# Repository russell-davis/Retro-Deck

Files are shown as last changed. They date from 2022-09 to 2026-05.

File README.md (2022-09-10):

# Retro Deck

*A programmable 8-key macro pad built on a [Raspberry Pi Pico](https://www.raspberrypi.com/products/raspberry-pi-pico/?variant=raspberry-pi-pico-w) with [CircuitPython](https://circuitpython.org/).*

### Credit where credit is due
I only adapted these designs. The real credit goes to the following people, without whom this project would not have been possible:
- Based on DaveM's [Stream Cheap](https://www.thingiverse.com/thing:2822140), the retro deck adds a slot for a screen mount to be inserted and uses a Pico instead of an Arduino Pro Micro. Dave outlines the steps to build a stream cheap [on his website](https://www.partsnotincluded.com/diy-stream-deck-mini-macro-keyboard/).
- The [Monitor](https://www.thingiverse.com/thing:3548757) was designed by TucksProjects.

## Goals I had for this project
- 3D print 8 key macro pad
- long press a key to activate a profile
- short press a key to activate the macro
- display current mode and last macro run on screen

## Bill of Materials
| Item | Qty | Price | Link |
|---|-----|---|---|
| Raspberry Pi Pico | 1 | 4-23 USD | [Adafruit (single)](https://www.adafruit.com/product/4864) • [Amazon (3pack)](https://www.amazon.com/dp/B08ZSKMJJD?ref=ppx_yo2ov_dt_b_product_details&th=1) |
| Switches | 1 | 14 USD | [Amazon](https://www.amazon.com/dp/B098BGPT6W?ref=ppx_yo2ov_dt_b_product_details&th=1) |
| Key Caps | 1 | 8 USD | [Amazon](https://www.amazon.com/dp/B01M023NFK?ref=ppx_yo2ov_dt_b_product_details&th=1) |
| Oled Screen | 1 | 7 USD | [Amazon](https://www.amazon.com/dp/B072Q2X2LL?psc=1&ref=ppx_yo2ov_dt_b_product_details) |
| Threaded Inserts  | 1 | 18 USD | [Amazon](https://www.amazon.com/dp/B08YYGRCBG?psc=1&ref=ppx_yo2ov_dt_b_product_details) |
| Hex Socket Bolts  | 1 | 19 USD | [Amazon](https://www.amazon.com/dp/B09D3DFHH4?psc=1&ref=ppx_yo2ov_dt_b_product_details) |
| Development Board | 1 | 15 USD | [Amazon](https://www.amazon.com/dp/B093GXJ64J?psc=1&ref=ppx_yo2ov_dt_b_product_details) |

## Contributing
Any help is appreciated. If you have any questions, feel free to reach out.

If you have any suggestions or improvements, please create a [feature request here](https://github.com/russell-davis/Retro-Deck/issues/new?template=feature_request.md) or [start a pull request here](https://github.com/russell-davis/rlukedavis.com/compare/)

Likewise, bugs reports can be submitted [here](https://github.com/russell-davis/Retro-Deck/issues/new?template=bug_report.md).

## A very quick Q&A
- **Why did you use a Pico instead of an Arduino Pro Micro?**
  - I like Raspberry Pi's, hadn't used a Pico yet, and had $6. I also wanted to try out CircuitPython.
- **Can it launch apps?**
  - If you can launch it with a keyboard shortcut, then yes*.
  - *I haven't tried though. I'm primarily using it to with keyboard shortcuts that are more complicated than I want to remember.
- **Can I use it to play games?**
  - Sure, I guess. I haven't tried it yet. I imagine you'll have some ghosted keys, as this codebase is not rock solid (yet).
- **Your code is shit.**
  - I know. I'm working on it. Please contribute by starting [a feature request](https://github.com/russell-davis/Retro-Deck/issues/new?template=feature_request.md) to make it better

# Configuration

### mappings.json
The easiest way to get started configuring your Retro Deck is to duplicate and rename the `example-mappings.json` copy to `mappings.json` and edit it to represent your wiring.

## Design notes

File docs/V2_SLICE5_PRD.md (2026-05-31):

# V2 Slice 5 — Reliability + Diagnostics

## Why

Two issues block daily use of the Retro Deck:

1. **Keyboard "hijacking."** The host emits keypresses via two separate `ydotool`
   processes (press, wait 30 ms, release — `dispatch.ts`). If anything interrupts
   that window (release process error, an overlapping double-fire, the daemon
   dying mid-press) a modifier (Ctrl/Shift/**Super**) is left held *down at the
   virtual-keyboard level, system-wide*. Every later keystroke then carries the
   stuck modifier — the device appears to "hijack" the whole keyboard.

2. **Mis-calibrated input.** Long/short presses fire more than once and chords
   behave inconsistently. Three root causes:
   - **No chord decision window.** Pressing 1+3 "together" sends `press 3 held=[]`
     then `press 1 held=[3]`; the host fires the single-button "3" action *and*
     the "1+3" chord, order depending on which switch lands first.
   - **No tap/hold/double-tap concept.** The device sends raw press/release; the
     host fires on every press. Hold slots aren't wired.
   - **One event per 10 ms loop.** The firmware drains only a single keypad event
     per `time.sleep(0.01)` tick, so near-simultaneous presses are serialized
     ~10 ms apart — it *manufactures* gaps that corrupt chord detection.
   - We can't currently distinguish "device emitted 2" from "host saw 1 twice"
     because there is no sequence number on the wire.

We will not guess thresholds. We instrument first, measure the real limits
(serial throughput, keypad debounce floor, injection latency), then build the
smart input engine on measured values.

## Non-goals (this slice)

- The smart tap/hold/double-tap/chord classifier (Slice 6 — needs data first).
- Replacing ydotool with a self-managed uinput device (future hardening note below).

## Deliverables

### A. Keyboard reliability (`host/src/server/keyboard.ts`, `dispatch.ts`)
- `emitChord(codes)` — press + release in **one** `ydotool key` invocation, so a
  modifier can never be stranded between two processes.
- `releaseAllModifiers()` — best-effort release of all L/R modifier codes.
- Call `releaseAllModifiers()` on daemon startup (clears leaks from a prior crash).
- `POST /api/panic` + a UI "release all keys" control.

### B. Instrumented firmware (`firmware/code.py`)
- Monotonic `seq` on every outbound message → host detects drops (seq gap) and
  duplicates (seq repeat).
- Drain the **entire** keypad event queue each loop; tighten loop to ~1 ms.
- `ready` reports `version`, `buttons`, `pins`, `debounce_ms`.
- Runtime `config` command: `heartbeat_ms` (0 = off, default), `debounce_ms`
  (recreates `keypad.Keys`). Instrumentation is opt-in; the device is quiet in
  normal use.
- `ping`/`pong` echoes the host timestamp (`ht`) so the host measures round-trip
  latency with no clock sync.
- Backward compatible: extra fields are ignored by the existing host paths.

### C. Deploy tooling (`host/scripts/deploy.ts`, `bun run deploy`)
- Find CIRCUITPY by filesystem label (never a hardcoded path), mount via
  `udisksctl` if needed, copy `firmware/code.py` + `firmware/boot.py`, rsync
  `lib/`, `sync`. `--eject` to unmount. Target < 10 s.

### D. Diagnostics core + CLI + web tab (`host/src/server/diagnostics.ts`, `scripts/diag.ts`, client `Diagnostics` tab)
- Shared analyzer: per-button state, inter-press gaps, press→release durations,
  dropped/duplicate frames (via seq), device-`t`-vs-host-arrival latency + jitter,
  sustained events/sec, ping/pong RTT.
- Scripted test routines: tap×N, hold, double-tap, rapid-fire, two-button chord,
  all-buttons, and a ping stress test to find the serial ceiling.
- CLI for remote/SSH use; web tab for live timeline + gauges. Both consume the
  same core and can replay a recorded capture (so it's testable without hardware).

### E. Smart input engine — Slice 6, deferred
Host-side classifier (debounce floor, chord window, double-tap gap, hold
duration) tuned from Slice 5 measurements.

## Future hardening note
ydotool injects through `ydotoold`'s virtual keyboard, which outlives our daemon —
that's why a leaked modifier persists. A self-managed `/dev/uinput` device owned
by the daemon process would let the kernel auto-release all keys the instant the
daemon exits. Tracked for a later slice.

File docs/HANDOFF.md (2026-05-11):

# Retro Deck V2 Rewrite

## What This Is

The Retro Deck is a physical 8-key macro pad built on a Raspberry Pi Pico running CircuitPython. The original codebase was written before the owner knew what they were doing — it works, but it's messy and limited. This V2 rewrite starts from scratch with a clear goal: turn the Retro Deck into a first-class **agent tool** — a physical peripheral that can trigger, interact with, and be controlled by Claude Code agents or other AI workflows.

## Goal for This Session

Design and implement the V2 architecture. The rewrite should be clean, intentional CircuitPython — but more importantly, the device should be capable of acting as a hardware input/output bridge for agent-driven workflows. What that means exactly is an open question to explore with the user at session start.

## Decisions Already Made

- **Branch**: `feature/v2-rewrite` (on `russell-davis/Retro-Deck`)
- **Hardware**: Raspberry Pi Pico, 8 mechanical switches, OLED display, CircuitPython
- **Scope**: Full rewrite — don't salvage the old `code.py`, start clean
- **Direction**: Make it an "agent tool" — the device should be useful as part of an AI/Claude workflow, not just a standalone macro pad

## What's Been Done

- Cloned repo to `~/Work/retro-deck`
- Created branch `feature/v2-rewrite`

## Start Here

1. Read the existing `code.py` and `example-mappings.json` to understand what V1 did
2. Read `src/` and `lib/` to see what modules exist
3. Ask the user: **"What does 'agent tool' mean to you here?"** — does the Pico talk to the host over serial USB? Does it trigger webhooks? Does it register as a HID device that sends signals to a running agent? The answer shapes the entire architecture.
4. Once direction is clear, design the V2 module structure before writing any code

## Open Questions

- What is the communication model? (USB serial, HID, USB CDC, webhook, other?)
- Should the device be host-driven (agent sends commands to Pico) or device-driven (Pico sends events to agent)?
- Does the OLED display get driven by the Pico itself, or can the host push display content?
- Should profiles/macros still exist in V2, or is the key mapping entirely agent-controlled?
- Config format: keep JSON, or move to something simpler/more expressive?

## References

- Original repo: `https://github.com/russell-davis/Retro-Deck`
- Existing code: `code.py`, `example-mappings.json`, `src/`, `lib/`
- CircuitPython docs: `https://docs.circuitpython.org`
- Device is currently plugged in at `/dev/sda1` (label: `CIRCUITPY`) — not auto-mounted

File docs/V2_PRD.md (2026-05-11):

# Retro Deck V2 — Product Requirements Document

> **Status:** Draft v1
> **Audience:** Implementation team, issues writer, future maintainers
> **Source of truth for V1 state:** `V2_REWRITE_ANALYSIS.md`
> **Owner:** rld

---

## 1. Overview

Retro Deck V2 is a ground-up rewrite of the firmware, host integration, and configuration tooling for an 8-key + OLED USB macro pad built on a Raspberry Pi Pico (RP2040, CircuitPython). V1 is a self-contained HID emitter: every button is wired in Python to a hardcoded keystroke, and the host has no idea the device exists beyond stock USB descriptors. V2 inverts that relationship.

In V2, the **host owns the brains** and the **Pico is a thin I/O peripheral**:

- The Pico reports raw button events (press / hold / release with durations) and renders whatever the host tells it to render on the OLED.
- A host-side **Bun/TypeScript daemon** owns the config, dispatches actions, drives the OLED, and exposes hooks (e.g. for Claude Code) that other processes can call.
- A **configuration UI** edits the config live, and the daemon hot-reloads it.
- Three distinct **action types** are supported per button: `keypress` (Pico emits HID directly), `bash` (host shell command), and `function` (host TypeScript module imported and invoked).
- **Profiles** are infinite, named, and stored on the host. Switching is host-driven, with a configurable on-device gesture (default: long-press a designated button).

The result: any new behaviour — a deploy command, an "approve PR" hotkey, a Claude Code "yes/no" prompt, a new profile for a different app — is a config edit on the host, not a firmware re-flash.

---

## 2. Goals & Non-Goals

### 2.1 Goals

| # | Goal | Why it matters |
|---|---|---|
| G1 | Two-way structured comms over USB CDC between Pico and host | Unblocks every other goal |
| G2 | Host-owned config, hot-reloadable, no firmware edits to add/change actions | Configuration is a TypeScript/JSON workflow, not a CircuitPython workflow |
| G3 | Three action types: `keypress`, `bash`, `function` | Covers the realistic action surface (HID, shell, custom TS logic) |
| G4 | Infinite named profiles with host-driven switching | Removes V1's hardcoded 3-profile / IndexError limit |
| G5 | Host pushes display content; OLED shows current profile + per-button labels | The user can read what each button does without pressing it |
| G6 | Non-blocking firmware loop (asyncio) — concurrent button + serial + display | No more `time.sleep(1.5)` stalling the entire device |
| G7 | Persistent active profile across reboots (host-side) | Reboot resumes where you left off |
| G8 | Configuration UI (TUI or webapp) showing all profiles, all 8 slots, live device state | Editing JSON by hand is fine but not the primary workflow |
| G9 | Deploy tooling for fast firmware iteration (CIRCUITPY mount/rsync/unmount) | A code-edit/test cycle of seconds, not minutes |
| G10 | Graceful error reporting from device to host (and to user via OLED) | Replace V1's silent drop-to-REPL on exceptions |
| G11 | Claude Code hook integration via HTTP endpoints on the daemon | Use the deck as an approval surface for agent prompts |

### 2.2 Non-Goals

| # | Non-goal | Reason |
|---|---|---|
| NG1 | WiFi / Bluetooth / network comms from the Pico | Hardware is base Pico (no W). USB is sufficient. |
| NG2 | Multi-host / multi-device pairing | One Pico, one host. Identity disambiguation deferred. |
| NG3 | Per-key RGB or per-key LCD | Hardware is monochrome SSD1306 OLED + plain switches. |
| NG4 | Cross-OS support beyond Linux | Owner runs Linux (Arch/Omarchy). macOS/Windows untested in V2. |
| NG5 | Encryption / authentication on the serial channel | USB-attached peripheral on a single-user machine. |
| NG6 | Replacing CircuitPython with MicroPython or bare-metal | CircuitPython is intentionally chosen for iteration speed. |
| NG7 | Backwards compatibility with V1 profiles or `mappings.json` schema | Clean break. V1 is removed. |
| NG8 | OTA firmware updates over USB CDC | Deploy is a host-side rsync to CIRCUITPY mount. |
| NG9 | Mouse / consumer-control HID in v2.0 | Bundled libs exist; deferred to v2.1+. |

### 2.3 Success Criteria

- A new action can be added by editing a single JSON file on the host and saving — no firmware reflash, no daemon restart.
- A new profile can be added the same way.
- The OLED shows the active profile name persistently and updates within 100ms of a profile switch.
- All 8 buttons work for press, hold (with duration), and release events. No button gesture crashes the firmware.
- The daemon survives Pico unplug/replug without a manual restart.
- `bun run deploy` syncs firmware to the device in under 10 seconds.

---

## 3. System Architecture

### 3.1 ASCII Diagram

```
 ┌──────────────────────────────────────────────────────────────────────┐
 │                              HOST (Linux)                            │
 │                                                                      │
 │   ┌──────────────────┐     ┌────────────────────┐    ┌─────────────┐ │
 │   │   Config UI      │     │   retro-deckd      │    │  Claude     │ │
 │   │   (TUI/webapp)   │◄───►│  (Bun/TS daemon)   │◄──►│  Code /     │ │
 │   │                  │ HTTP│                    │HTTP│  external   │ │
 │   │  - profile list  │     │  ┌──────────────┐  │    │  tools      │ │
 │   │  - 8 slots/prof  │     │  │ ConfigStore  │  │    └─────────────┘ │
 │   │  - live state    │     │  │ (JSON, hot-  │  │                    │
 │   │  - test buttons  │     │  │  reloaded)   │  │                    │
 │   └──────────────────┘     │  └──────┬───────┘  │                    │
 │                            │         │          │                    │
 │   ┌──────────────────┐     │  ┌──────▼───────┐  │                    │
 │   │ ~/.config/       │◄───►│  │ ActionExec   │  │                    │
 │   │ retro-deck/      │ R/W │  │ (keypress/   │  │                    │
 │   │   config.json    │     │  │  bash/fn)    │  │                    │
 │   │ ~/.local/share/  │     │  └──────┬───────┘  │                    │
 │   │ retro-deck/      │     │         │          │                    │
 │   │   state.json     │     │         │          │                    │
 │   └──────────────────┘     │         │          │                    │
 │                            │  ┌──────▼───────┐  │                    │
 │                            │  │ SerialMgr    │  │                    │
 │                            │  │ (CDC, JSONL) │  │                    │
 │                            │  └──────┬───────┘  │                    │
 │                            └─────────┼──────────┘                    │
 │                                      │ /dev/ttyACM1                  │
 └──────────────────────────────────────┼───────────────────────────────┘
                                        │ (USB CDC + USB HID, same cable)
 ┌──────────────────────────────────────┼───────────────────────────────┐
 │                              DEVICE  │ (Pi Pico, CircuitPython)      │
 │                                      │                               │
 │                   ┌──────────────────▼───────────┐                   │
 │                   │       code.py (asyncio)      │                   │
 │                   │                              │                   │
 │  ┌─────────────┐  │  ┌────────────────────────┐  │  ┌─────────────┐  │
 │  │ 8 switches  ├─►│  │ ButtonScanner (keypad) ├──┼─►│ usb_cdc.data│  │
 │  │ GP20,19,18, │  │  └────────────────────────┘  │  │ (events out)│  │
 │  │ 17,11,12,   │  │                              │  └─────────────┘  │
 │  │ 13,14       │  │  ┌────────────────────────┐  │                   │
 │  └─────────────┘  │  │ SerialReader (cmds in) ◄──┼──┐                │
 │                   │  └──────────┬─────────────┘  │  │                │
 │  ┌─────────────┐  │             │                │  │                │
 │  │ SSD1306     │◄─┼──┌──────────▼─────────────┐  │  │                │
 │  │ OLED 128x64 │  │  │ DisplayRenderer        │  │  │                │
 │  │ I2C GP0/1   │  │  └────────────────────────┘  │  │                │
 │  └─────────────┘  │                              │  │                │
 │                   │  ┌────────────────────────┐  │  │                │
 │  ┌─────────────┐  │  │ HIDEmitter (Keyboard)  │◄─┼──┘                │
 │  │ USB HID     │◄─┼──┤ for "keypress" actions │  │                   │
 │  └─────────────┘  │  └────────────────────────┘  │                   │
 │                   └──────────────────────────────┘                   │
 └──────────────────────────────────────────────────────────────────────┘
```

### 3.2 Roles at a glance

| Layer | Owns | Does NOT own |
|---|---|---|
| **Pico firmware** | Button scanning, HID emission for `keypress` actions, OLED rendering, serial framing | Action dispatch, profiles, action semantics, what to show |
| **Host daemon** | Config, profiles, action execution (`bash`/`function`), display content decisions, persistence, external HTTP integrations | Raw button electricals, HID emission for keypress (Pico does this directly to reduce latency), OLED pixel drawing |
| **Config UI** | Editing experience, validation, "test" affordances | Live action execution (delegates to daemon), serial comms |

### 3.3 Why the Pico emits keypress HID directly (not via the host)

For `keypress` actions, the Pico has the HID device on the same USB connection and can emit a keystroke immediately on button press without a host round-trip. The action **type** is configured on the host, but for `keypress` actions the **actual keys** are pushed to the Pico (via a `bind` message — see §9) so it can fire them with zero host involvement during the press. This keeps `keypress` latency at hardware speed and avoids a "host crashed → keys don't work" failure mode for the most common action type.

`bash` and `function` actions go through the host because they have to.

---

## 4. Component 1: Pico Firmware (CircuitPython)

### 4.1 Responsibilities

The Pico firmware is intentionally minimal:

1. Scan 8 buttons; emit press / hold-tick / release events with millisecond timestamps over USB CDC.
2. Render OLED content as instructed by the host (header, per-button labels, transient toasts, error banners).
3. Emit USB HID keystrokes for buttons that have been bound to a `keypress` action by the host.
4. Maintain a small in-memory cache of: current profile name, per-button labels, per-button keypress bindings.
5. On boot, send a `ready` handshake and wait for the host to push initial state.
6. Surface fatal errors as a banner on the OLED *before* dropping to REPL.

The firmware does **not** know:

- What profiles exist (only the currently active one's labels and bindings).
- What `bash` or `function` actions exist (those are entirely host-side).
- How to switch profiles by itself (it sends a "long-press" event; the host decides what that means).

### 4.2 boot.py requirements

`boot.py` must enable USB CDC data channel (the second serial endpoint):

```python
# boot.py
import usb_cdc
usb_cdc.enable(console=True, data=True)  # data=True enables /dev/ttyACM1
```

**Notes:**
- `console=True` keeps the REPL on `/dev/ttyACM0` so we can still debug via Mu/Thonny/screen.
- `data=True` adds the second endpoint at `/dev/ttyACM1` — this is the channel used by the host daemon. *(Exact device path may vary by enumeration order; the host daemon must auto-discover via VID/PID or by trying `/dev/ttyACM*` and looking for the `ready` handshake.)*
- `boot.py` runs at hard reset and is what configures USB endpoints (which can only be set up before USB enumeration). Soft reload does not re-run it.

### 4.3 Serial Protocol (overview, full spec in §9)

- **Transport:** USB CDC, `usb_cdc.data` endpoint (`/dev/ttyACM1`).
- **Encoding:** UTF-8.
- **Framing:** newline-delimited JSON (JSONL). Each message is a single-line JSON object terminated by `\n`. Values must be valid JSON — embedded newlines inside string values are JSON-escaped (`\n`) per the spec; the line delimiter is the literal byte `0x0A` outside any string token.
- **Direction tags:** Each message has a `type` field. Pico→Host messages are reactive/eventy; Host→Pico messages are imperative/setter-y.
- **Versioning:** A `protocol` field is sent only in the `ready` and `hello` handshake messages (see §9). All other messages omit it; both sides assume the version handshake.

### 4.4 Button event model

Three event types are emitted per button, all reaching the host:

| Event | When | Payload |
|---|---|---|
| `press` | Edge: button transitions from released to pressed | `{ id, t }` |
| `hold` | Every 250ms while held, after the first 500ms | `{ id, t, duration_ms }` |
| `release` | Edge: button transitions from pressed to released | `{ id, t, duration_ms }` |

- `id`: 1–8, the logical button index (post-mapping, see §6.2).
- `t`: monotonic milliseconds since Pico boot (`supervisor.ticks_ms()`).
- `duration_ms`: total time held so far (for `hold`) or total time pressed (for `release`).

**Press semantics on the host:**
- A *short press* is a `press` followed by a `release` with `duration_ms < long_press_ms` (default 1500ms; configurable).
- A *long press* is a `release` with `duration_ms >= long_press_ms` (or, equivalently, the host can act on the first `hold` event whose `duration_ms` crosses the threshold for instant feedback).
- The host owns the threshold; the Pico just streams raw events.

**Implementation:** Use CircuitPython's `keypad.Keys` for non-blocking, debounced edge detection. Run the scanner inside an asyncio task at ~100Hz tick (the library does its own debouncing).

### 4.5 OLED rendering model

The OLED has three render zones:

```
 ┌──────────────────────────────┐
 │ HEADER       (line 1, small) │   ← profile name, e.g. "OBS"
 ├──────────────────────────────┤
 │                              │
 │   BODY      (lines 2–6)      │   ← 8 button labels in a 4x2 grid,
 │                              │     OR transient toast,
 │                              │     OR error banner (overrides body)
 │                              │
 ├──────────────────────────────┤
 │ STATUS  (line 7, small)      │   ← e.g. "● ready"  /  "● running…"
 └──────────────────────────────┘
```

- Default body: a 4×2 grid of button labels (buttons 1–4 top row, 5–8 bottom row). Labels truncated to fit.
- Toast: a transient large-font centred message after a press (configurable TTL, default 1500ms), then revert to grid.
- Error banner: full-body inverted (white-on-black) message with the most recent error, until cleared by host or auto-dismissed after `display.errorTtlMs`.

The host pushes content via `display.set_layout`, `display.toast`, `display.error`, `display.clear_error` messages (see §9). The Pico does no semantic decision-making about display state; it renders what it's told.

**Font:** `terminalio.FONT` (built-in 6×8 monospace) for v2.0. If labels need to be longer than ~10 chars per cell, v2.1 can vendor `adafruit_display_text` source `.py` and add scrolling — but v2.0 truncates with an ellipsis.

### 4.6 HID for keypress actions

- The Pico keeps a dict `keypress_bindings: dict[int, list[str]]` — button id → list of keycode names (e.g. `["CONTROL", "SHIFT", "R"]`).
- This dict is populated on profile-load by a `bind.set` message from the host.
- On a `press` event, the Pico checks the dict and (if a binding exists) emits the HID report immediately, then releases the keys after a short delay (~30ms) — simulating a tap.
- Only `keypress` actions populate the dict. `bash` and `function` actions do not — those buttons send their event to the host and let the host do the work.
- The Pico still emits the `press`/`release` events to the host even if it fires a HID report locally — the host is the system of record for "what just happened."

**Keycode parsing:** The host sends keys as a list of canonical names (e.g. `["CONTROL", "SHIFT", "F5"]`). The Pico maps these to `adafruit_hid.keycode.Keycode` attributes by `getattr`. Unknown names cause the binding to be rejected with an `error` reply naming the bad key.

### 4.7 asyncio loop design

CircuitPython 8+ ships with `asyncio`. The main loop is a small set of cooperating tasks:

```python
async def main():
    await asyncio.gather(
        button_scanner_task(),     # keypad.Keys → emit events
        serial_reader_task(),      # usb_cdc.data → parse JSON → dispatch
        display_render_task(),     # subscribe to display state changes
        heartbeat_task(),          # emit a "tick" every 5s for liveness
    )
```

- Tasks communicate via `asyncio.Queue` instances.
- The serial reader is a pure router: it parses a line, validates `type`, and pushes onto the appropriate queue (display queue / bindings queue / etc.).
- No `time.sleep()` anywhere — every wait is `await asyncio.sleep(...)`.
- Errors caught at task boundary and reported to host via an `error` message; firmware does not crash.

### 4.8 Persistence on the Pico

- **None.** The Pico does not remember the active profile, last action, or anything else across reboots.
- The host pushes the full state on every connect (`hello` from the host, in response to the Pico's `ready`).
- This keeps the Pico stateless and the host as single source of truth.

### 4.9 GPIO mapping

Hardware pin assignments are unchanged from V1:

| Button id | GPIO |
|---|---|
| 1 | GP20 |
| 2 | GP19 |
| 3 | GP18 |
| 4 | GP17 |
| 5 | GP11 |
| 6 | GP12 |
| 7 | GP13 |
| 8 | GP14 |

OLED I2C: SDA=GP0, SCL=GP1, address `0x3C`.

The pin-to-button map is hardcoded in firmware as a constant. Remapping is not a runtime feature in v2.0 (V1's `mappings.json` is removed) — if a re-wire happens, edit the constant and reflash. Rationale: the case is 3D-printed and the wiring is fixed.

### 4.10 Module structure (target)

```
firmware/
  boot.py                    # enable usb_cdc.data
  code.py                    # asyncio main, glue
  retro/
    __init__.py
    protocol.py              # JSON message dataclasses, serializer/parser
    buttons.py               # keypad.Keys wrapper, event emission
    serial_io.py             # usb_cdc.data read/write tasks
    display.py               # OLED state machine + render
    hid.py                   # keypress binding store + emit
    state.py                 # in-memory state (current profile name, labels, bindings)
  lib/
    adafruit_hid/            # carry forward from V1
    adafruit_displayio_ssd1306.py
    adafruit_display_text/   # carry forward (still .mpy unless we vendor)
    # asyncio is built into CircuitPython 8+ — do NOT vendor it
```

---

## 5. Component 2: Host Daemon (Bun/TypeScript)

### 5.1 Responsibilities

The daemon (working name: `retro-deckd`) is a long-running Bun process that:

1. Discovers and connects to the Pico via USB CDC.
2. Loads the user's config from `~/.config/retro-deck/config.json`.
3. Tracks the active profile (persisted in `~/.config/retro-deck/state.json`).
4. On Pico `ready`: pushes the active profile's labels, key bindings, and display content.
5. On button events: looks up the action for that button in the active profile and executes it.
6. Hot-reloads config when the file changes on disk.
7. Exposes an HTTP control API (localhost) for the config UI and external integrations.
8. Handles Pico unplug/replug gracefully (auto-reconnect with backoff).
9. Logs structured events to a rotating log file in `~/.local/share/retro-deck/logs/`.

### 5.2 Process lifecycle

- **Startup:** read config → validate → discover serial port → connect → wait for `ready` → push initial state → enter event loop.
- **Shutdown:** on SIGTERM/SIGINT, send a final `display.toast` ("daemon stopped"), close the serial port cleanly, save state, exit.
- **Run mode:** intended to be run as a systemd user service (`retro-deckd.service`) for `omarchy-desktop`. The PRD does not mandate the unit file, but the daemon must be 12-factor-friendly: foreground-by-default, log to stdout, exit non-zero on fatal error.

### 5.3 Serial Port Manager

- **Discovery:** scan `/dev/ttyACM*` (and `/dev/serial/by-id/*` as a robustness pass), open each non-busy candidate, and **listen for an incoming `ready` line** for up to 1500ms. The Pico emits `ready` on its own at boot; the host does not provoke it. The first port that yields a valid `ready` with the expected `protocol` and `app: "retro-deck"` wins. If no candidate emits a `ready` within the window, the daemon backs off and rescans (the Pico may be mid-reset). After connect, the host replies with `hello` (see §9.5).
- **Connect:** open the port via the [`serialport`](https://serialport.io/) npm package (Bun has working Node-compat for it). USB CDC ignores baud; pick any value (e.g. 115200). Configure for non-blocking reads.
- **Read loop:** buffer incoming bytes; split on `\n`; parse each line as JSON; dispatch by `type`.
- **Write:** every outbound message is `JSON.stringify(msg) + "\n"`. Writes are queued per-connection; never interleave half-messages.
- **Reconnect:** if the read loop sees EOF or an error (Pico unplugged), back off (250ms → 500ms → 1s → 2s, max 5s) and re-discover. On re-connect, re-push the full active state.

### 5.4 Action Executor

The daemon listens to **all** button event types (`press`, `hold`, `release`) but only takes action-dispatch decisions on `release`. `press` and `hold` are used for live state (e.g. SSE clients showing "button 3 down") and for early long-press feedback (the daemon may show a toast as soon as the first `hold` event crosses the threshold, without waiting for `release`). Note that for `keypress` actions, the **Pico** has already fired the HID at `press` time independently — the host's dispatch path is unrelated to that.

For each `release` event, the daemon:

1. Determines if it was a short or long press (using `duration_ms` and the configured threshold).
2. Looks up the action in `config.profiles[active].buttons[id]`.
3. For long-press on the configured *profile-switch button*, cycles or selects a profile (see §6.3) instead of executing the action.
4. Otherwise, dispatches by `action.type`:

| `action.type` | Behaviour |
|---|---|
| `keypress` | **No host-side execution.** The Pico already fired the HID at `press` time. The host does not enter the per-button concurrency queue for keypress actions — it only logs the event and updates the OLED status to "● done". |
| `bash` | `Bun.spawn` the command in a shell. stdout/stderr captured to log. Status updates pushed to OLED: `running…` → `done` / `error: <stderr-tail>`. Exit code surfaced. Default working dir: `$HOME`. Override per-action via `action.cwd` (see §6.4.2). Default timeout: 30s (override via `action.timeoutMs`). |
| `function` | Dynamically `await import(modulePath)` — module must export a default async function `(ctx) => Promise<void \| {message?: string}>`. `ctx` provides logging, OLED toast, and access to env. Module is cached; hot-reload invalidates the cache. |
| `noop` | No execution; emits a `✓ <label>` toast for user feedback. |

**Concurrency:** `bash` and `function` actions execute in order per button (no overlap — a second press while the first action is still running is queued, capped at 1 queued event; further presses dropped with a "busy" toast). `keypress` actions never enter this queue. Different buttons run concurrently.

**Action timeout handling:** on timeout, send SIGTERM to the action's process; SIGKILL 5s later if still alive. Display a `✗ timeout` toast and log the killed action.

**Action result reporting:**
- Success: `display.toast("✓ <action-name>")` for 1500ms.
- Failure: `display.toast("✗ <error-summary>")` for 3000ms, plus full error logged.

### 5.5 Config loader + hot-reload

- Source: `~/.config/retro-deck/config.json` (XDG-compliant).
- On startup: read, parse, validate against schema (§6). Fail hard on invalid config (log the error, exit non-zero) — invalid config is a user error, not a runtime exception.
- Hot-reload: watch the file with [`fs.watch`](https://nodejs.org/api/fs.html#fswatchfilename-options-listener) (debounced 250ms). On change: re-validate; if valid, swap the in-memory config atomically and re-push the active profile to the Pico. If invalid, log error and *keep the previous config running* — do not crash.
- A successful hot-reload pushes a brief OLED toast: `config reloaded`.

### 5.6 Persistence

- `~/.config/retro-deck/config.json` — user-edited config (read-only from daemon's perspective, except via the config UI's HTTP API which writes through the daemon to the file).
- `~/.local/share/retro-deck/state.json` — daemon-managed runtime state. Schema:
  ```json
  { "activeProfile": "obs", "lastUpdated": "2026-05-09T12:34:56Z" }
  ```
- State is written on every profile switch, atomically (`write-tmp + rename`).

### 5.7 HTTP control API

The daemon binds an HTTP server on `127.0.0.1:7842` (configurable). All endpoints are JSON.

| Method | Path | Purpose |
|---|---|---|
| `GET` | `/health` | `{ ok: true, connected: bool, activeProfile: string }` |
| `GET` | `/config` | Current parsed config |
| `PUT` | `/config` | Replace config (writes to file → triggers hot-reload). Body: full config JSON. |
| `GET` | `/profiles` | List of profile names |
| `POST` | `/profiles/:name/activate` | Switch to a named profile |
| `POST` | `/buttons/:id/test` | Trigger button `id`'s action manually (for the config UI's "test" button) |
| `GET` | `/state` | Snapshot of in-memory state: connected, active profile, last events, last error |
| `GET` | `/events` | Server-Sent Events stream of button events + state changes (for live UI) |
| `POST` | `/display/toast` | `{ message, ttl_ms? }` — push a toast to the OLED. Used by Claude Code hooks. |
| `POST` | `/display/prompt` | `{ message, options: [{button, label}], timeout_ms? }` — show a prompt with per-button labels; resolve when the user presses one of the listed buttons or the timeout elapses. Used by Claude Code "approve / deny" workflows. Returns `{ chosen: string \| null }`. |

The config UI consumes this API. So can any other tool — Claude Code hooks call `/display/toast` and `/display/prompt`.

### 5.8 Claude Code hook integration

Claude Code hooks (configured in user settings) can shell out to `curl http://127.0.0.1:7842/display/...`. The daemon must:

- Make `/display/toast` non-blocking, returning 202 immediately.
- Make `/display/prompt` blocking (long-poll) up to the timeout, suitable for use as a hook that gates the next agent action.
- Accept basic-auth-free localhost-only connections in v2.0; revisit if the daemon ever binds to a non-loopback address.

**Reference hook example** (`~/.claude/settings.json`):

```json
{
  "hooks": [
    {
      "matcher": "Bash",
      "hooks": [
        {
          "type": "command",
          "command": "curl -s -X POST http://127.0.0.1:7842/display/prompt -H 'Content-Type: application/json' -d '{\"message\":\"Run bash?\",\"options\":[{\"button\":1,\"label\":\"yes\"},{\"button\":8,\"label\":\"no\"}],\"timeout_ms\":15000}' | jq -r 'if .chosen==\"yes\" then \"\" else \"deny\" end'"
        }
      ]
    }
  ]
}
```

The daemon doesn't need to know about Claude Code specifically — the integration is just HTTP.

### 5.9 Module structure (target)

```
host/
  package.json              # Bun project
  bunfig.toml
  src/
    daemon.ts               # entry point: starts everything
    config/
      schema.ts             # zod schema + validator
      loader.ts             # read/parse/watch
      types.ts              # TS types derived from schema
    serial/
      manager.ts            # discovery + connect + reconnect
      protocol.ts           # JSON message types (mirror firmware/retro/protocol.py)
    actions/
      executor.ts           # dispatch by action.type
      keypress.ts           # logging only (Pico does emission)
      bash.ts               # Bun.spawn wrapper
      function.ts           # dynamic import + invoke
    display/
      controller.ts         # owns "what should be on the OLED right now"
      layouts.ts            # builds layout messages from profile data
    state/
      store.ts              # in-memory + file-backed state
    http/
      server.ts             # Bun.serve
      routes.ts             # endpoint handlers
      sse.ts                # /events stream
    integrations/
      claude-code.ts        # helpers for /display/prompt-as-gate
  scripts/
    deploy.ts               # firmware deploy (see §8)
  tests/
    ...
```

---

## 6. Component 3: Config Format

### 6.1 Top-level schema

The host config is a single JSON file, hand-editable but normally edited via the config UI.

```jsonc
{
  "$schema": "https://retro-deck/v2-config.schema.json",
  "version": 2,

  "device": {
    "longPressMs": 1500,
    "profileSwitchButton": 8,        // long-press button 8 to cycle profiles
    "profileSwitchMode": "cycle"     // "cycle" | "menu" — see §6.3
  },

  "display": {
    "toastTtlMs": 1500,
    "errorTtlMs": 5000,
    "defaultStatus": "ready"
  },

  "http": {
    "host": "127.0.0.1",
    "port": 7842
  },

  "profiles": {
    "default": {
      "label": "Default",
      "buttons": {
        "1": { "label": "BTN 1", "action": { "type": "keypress", "key": "ctrl+shift+r" } },
        "2": { "label": "test",  "action": { "type": "bash", "cmd": "bun test" } },
        "3": { "label": "deploy","action": { "type": "function", "module": "./actions/deploy.ts" } },
        "4": { "label": "noop",  "action": { "type": "noop" } },
        "5": { "label": "noop",  "action": { "type": "noop" } },
        "6": { "label": "noop",  "action": { "type": "noop" } },
        "7": { "label": "noop",  "action": { "type": "noop" } },
        "8": { "label": "mode",  "action": { "type": "noop" } }
      }
    },

    "obs": {
      "label": "OBS",
      "buttons": {
        "1": { "label": "black",   "action": { "type": "keypress", "key": "ctrl+alt+shift+1" } },
        "2": { "label": "soon",    "action": { "type": "keypress", "key": "ctrl+alt+shift+2" } },
        "3": { "label": "chat",    "action": { "type": "keypress", "key": "ctrl+alt+shift+3" } },
        "4": { "label": "edge",    "action": { "type": "keypress", "key": "ctrl+alt+shift+4" } },
        "5": { "label": "mic",     "action": { "type": "keypress", "key": "ctrl+alt+shift+5" } },
        "6": { "label": "video",   "action": { "type": "keypress", "key": "ctrl+alt+shift+6" } },
        "7": { "label": "t4w",     "action": { "type": "keypress", "key": "ctrl+alt+shift+7" } },
        "8": { "label": "mode",    "action": { "type": "noop" } }
      }
    }
  }
}
```

### 6.2 Profile structure

```ts
type Profile = {
  label: string;             // human-readable; shown in OLED header and UI
  buttons: Record<"1"|"2"|"3"|"4"|"5"|"6"|"7"|"8", ButtonSlot>;
};

type ButtonSlot = {
  label: string;             // shown in OLED grid (truncated to ~10 chars)
  action: Action;
};
```

All 8 button slots must be present in every profile (use `{ "type": "noop" }` for empty slots). This keeps the OLED grid stable when switching profiles.

### 6.3 Profile switching

- **`cycle` mode (default):** long-press the `device.profileSwitchButton`. Each long-press advances to the next profile in declaration order, wrapping at the end. The new profile name is displayed as a toast.
- **`menu` mode:** long-press the switch button → OLED shows a profile menu (one profile per line, paged if more than 4); subsequent short-presses on buttons 1–4 select; button 8 cancels. *(v2.1 — out of scope for v2.0.)*

The profile-switch button itself still has a `label` and `action` for short-presses — long-press is overloaded for switching and short-press fires the regular action.

### 6.4 Action type definitions

```ts
type Action =
  | { type: "keypress"; key: string }
  | { type: "bash"; cmd: string; shell?: string; cwd?: string; timeoutMs?: number }
  | { type: "function"; module: string; export?: string }   // export defaults to "default"
  | { type: "noop" };
// `shell` defaults to "bash -c"; `cwd` defaults to $HOME; `timeoutMs` defaults to 30000.
```

#### 6.4.1 `keypress`

- `key` is a `+`-separated string of human-friendly key tokens (case-insensitive). The host parses by: lowercase, strip whitespace, split on `+`, then map each token to a canonical `adafruit_hid.keycode.Keycode` attribute name via the alias table below. Canonical names are pushed to the Pico via `bind.set`.

**Token → canonical Keycode name (full alias table the host must implement):**

| Input token (lowercased) | Canonical name | Notes |
|---|---|---|
| `ctrl`, `control` | `CONTROL` | |
| `shift` | `SHIFT` | |
| `alt`, `option`, `opt` | `ALT` | |
| `cmd`, `super`, `win`, `windows`, `meta` | `WINDOWS` | |
| `a`..`z` | `A`..`Z` | uppercased |
| `0` | `ZERO` | |
| `1`..`9` | `ONE`..`NINE` | spelled out |
| `f1`..`f24` | `F1`..`F24` | uppercased |
| `tab` | `TAB` | |
| `enter`, `return` | `ENTER` | |
| `esc`, `escape` | `ESCAPE` | |
| `space`, `spacebar` | `SPACEBAR` | |
| `backspace` | `BACKSPACE` | |
| `delete`, `del` | `DELETE` | |
| `home` / `end` / `pageup` / `pagedown` | `HOME` / `END` / `PAGE_UP` / `PAGE_DOWN` | |
| `left`, `leftarrow` | `LEFT_ARROW` | analogous: `right`, `up`, `down` |
| `minus`, `-` | `MINUS` | |
| `equals`, `=` | `EQUALS` | |
| `,` | `COMMA` |  |
| `.` | `PERIOD` |  |
| `/` | `FORWARD_SLASH` |  |
| `\\` | `BACKSLASH` |  |
| `;` | `SEMICOLON` |  |
| `'` | `QUOTE` |  |
| `[` | `LEFT_BRACKET` |  |
| `]` | `RIGHT_BRACKET` |  |
| ``` ` ``` | `GRAVE_ACCENT` |  |

- Any token not in the alias table is passed through verbatim (uppercased) — e.g. `"KEYPAD_ZERO"` works as a literal canonical name.
- After mapping, the host validates each canonical name exists in `adafruit_hid.keycode.Keycode` (the daemon ships a generated list) and rejects the config on unknown names.
- The Pico does the final `getattr(Keycode, name)` resolution and rejects unknown names with an `error` message at `bind.set` time.

#### 6.4.2 `bash`

- `cmd` is the full command line (passed to `bash -c` or `shell` if specified).
- Stdout/stderr captured to log. Exit code drives toast (`✓` on 0, `✗` on non-zero).
- Long-running commands stream status to OLED status line every 1s.
- `cwd` defaults to `$HOME`.
- Default timeout: 30s. SIGTERM on timeout, SIGKILL 5s after that.
- Environment: inherits daemon env, with `RETRO_DECK_BUTTON=<id>` and `RETRO_DECK_PROFILE=<name>` exported.

#### 6.4.3 `function`

- `module` is a path resolvable from the directory of the config file (e.g. `./actions/deploy.ts`) — daemon resolves relative to `dirname(configPath)`.
- Module loaded via `await import(absolutePath)`. Bun handles TypeScript natively.
- Default export: `async (ctx: ActionContext) => void | { message?: string }`.
- `ActionContext` shape:
  ```ts
  type ActionContext = {
    button: number;           // 1–8
    profile: string;
    log: (msg: string) => void;
    toast: (msg: string, ttlMs?: number) => void;
    setStatus: (msg: string) => void;
    env: Record<string, string>;
  };
  ```
- Return value: if it returns `{ message }`, that becomes the success toast; otherwise the daemon shows `✓ <button-label>`.
- Throws → `✗ <error.message>` toast + logged.
- Hot-reload: when the config file changes OR the module file changes (watched), the import cache is cleared so the next press re-imports.

#### 6.4.4 `noop`

- Does nothing. Still emits a `✓` toast with the button's label so the user gets feedback. Used for "this slot is just for the OLED label" or "this is the profile-switch button."

### 6.5 Validation rules

The daemon validates the config on load (and on every hot-reload) using a [Zod](https://zod.dev) schema. Failures:

| Rule | On failure |
|---|---|
| `version` must equal `2` | Reject |
| At least one profile must exist | Reject |
| Every profile must have all 8 button keys (`"1"`–`"8"`) | Reject with the missing key |
| `device.profileSwitchButton` ∈ 1..8 | Reject |
| `keypress.key` parses to ≥1 known keycode | Reject with the bad token |
| `bash.cmd` is a non-empty string | Reject |
| `function.module` is a string ending in `.ts`, `.js`, or `.mjs` | Reject |
| `function.module` resolves to an existing file | Reject (only on initial load — hot-reload tolerates transient absence with a warning) |

Invalid config on **startup** → exit non-zero with a clear error.
Invalid config on **hot-reload** → log error, keep running with previous config.

### 6.6 Config file location

- Default: `~/.config/retro-deck/config.json`.
- Overridable via env var `RETRO_DECK_CONFIG=/path/to/config.json`.
- A bundled `examples/config.example.json` ships with the repo and is copied to the user's config dir on first run if no config exists.

---

## 7. Component 4: Configuration UI

### 7.1 Requirements

The UI must support:

1. **Browse profiles** — list all profiles with their labels.
2. **Edit a profile** — show all 8 button slots in a grid, each with editable label and action.
3. **Edit each action type** with the right form:
   - `keypress`: a "press keys to capture" input + manual keycode entry fallback.
   - `bash`: a single-line `cmd` field, optional `cwd`, optional `timeoutMs`.
   - `function`: a file picker for `module`, optional `export` field.
   - `noop`: just a toggle.
4. **Live device state** — show whether the daemon is connected, which profile is active, recent button events.
5. **Test a button** — fire its action without pressing the physical button (calls `POST /buttons/:id/test`).
6. **Activate a profile** — switch the active profile (calls `POST /profiles/:name/activate`).
7. **Validation feedback** — show errors inline before saving.
8. **Save** — `PUT /config` with the full updated config; daemon hot-reloads.

### 7.2 Recommended approach

Two viable options. The recommendation is **webapp**, but TUI is acceptable and faster to ship.

| | TUI (Ink / Bubble Tea-style) | Webapp (React + Bun static server) |
|---|---|---|
| **Time to ship** | Faster — single Bun binary, runs in terminal | Slower — needs frontend stack, build step |
| **Live updates** | Good (terminal redraws); SSE simple | Excellent (SSE → React state, animations) |
| **Key capture for keypress action** | Limited (terminal swallows or remaps modifiers; capturing `Ctrl+Shift+R` is awkward) | Native (`keydown` events with full modifier info) |
| **Discoverability** | Lower (need to know how to launch it) | Higher (open a tab, bookmark) |
| **Multi-window** | One terminal at a time | Multi-tab, multi-monitor |
| **Visual polish** | Constrained (text only, no colors-of-state for OLED preview) | Can render an actual SSD1306-look OLED preview |

**Recommendation:** Webapp using Bun's built-in static serving + a simple React frontend. Bind to `127.0.0.1:7843` (separate from the daemon's API port; the webapp itself just calls the daemon API).

**Rationale:** The "press keys to capture" affordance matters a lot for keypress actions, and only a browser gives reliable cross-platform key event data with all modifiers. The OLED preview pane is also genuinely useful and only feasible in HTML/CSS.

**Concrete starting stack:** `Bun.serve()` + React + TypeScript — **Tier 3A** per the project web stack standard. Single-page app served by a dedicated `server.ts` on port 7843. No Vite, no build step — Bun bundles the SPA from HTML imports on the fly. Dev and prod run the same `server.ts`. State syncs via SSE (`GET /events` from the daemon). TanStack Query for all data fetching against the daemon API on port 7842.

**Module layout (Tier 3A):**
```
host/ui/
  server.ts             # Bun.serve({ routes: { "/": index }, development: { hmr: true } })
  index.html            # <script type="module" src="./src/frontend.tsx">
  src/
    frontend.tsx        # createRoot, App entry
    components/
    queries/            # TanStack Query hooks → daemon API on :7842
    styles.css
```

**CORS:** The daemon's HTTP server (`host/src/http/server.ts`) must set `Access-Control-Allow-Origin: http://127.0.0.1:7843` (or `*` — localhost-only service) for the config UI to call it from the browser.

### 7.3 Out of scope for v2.0

- User-defined themes / custom CSS.
- Drag-and-drop reordering of profiles (rename + edit-in-place is sufficient).
- Profile import/export (just edit `config.json` directly).
- Multi-config-file support (one config file per host).

---

## 8. Component 5: Deploy Tooling

### 8.1 What it does

`bun run deploy` (`scripts/deploy.ts`) is the only sanctioned way to push firmware to the Pico. It:

1. **Detects the CIRCUITPY block device by filesystem label** (`lsblk -o LABEL,PATH -nr` or `blkid -L CIRCUITPY`). **Never** defaults to `/dev/sda1` or any other hardcoded path — that risks `rsync --delete`-ing the wrong disk on a multi-drive desktop.
2. Creates a mountpoint at `/run/media/$USER/CIRCUITPY` if not already mounted.
3. Mounts read-write (prefers `udisksctl mount` to avoid sudo; falls back to `sudo mount`).
4. `rsync -av --delete` the contents of `firmware/` to the mount.
5. `sync` to flush.
6. Unmounts cleanly (`udisksctl unmount` then `udisksctl power-off` if available).
7. Prints success and the timestamp.
8. *(Optional)* Tail the daemon log for 5s to surface any startup errors after Pico re-enumerates.

### 8.2 Behaviour and edge cases

- If no block device with label `CIRCUITPY` is found, exit non-zero with a helpful message ("plug in the Pico in BOOTSEL/CIRCUITPY mode").
- If the device is already mounted, reuse the existing mountpoint rather than re-mounting.
- `--device /dev/sdX1` overrides label-based detection (use only when sure).
- `--dry-run` prints what would be copied without touching anything.
- `--firmware <path>` overrides the default `./firmware` source dir.
- Refuse to proceed if the resolved device's label is anything other than `CIRCUITPY` (paranoia check).

### 8.3 Why a TS script (not a bash script)

- Consistent with the rest of the host stack (Bun/TypeScript).
- Easier to add structured options, argument parsing, and post-deploy verification.
- The repo's `package.json` exposes `bun run deploy` as the canonical command.

### 8.4 Permissions

Mounting/unmounting typically requires either:
- a polkit rule allowing `udisksctl mount/unmount` for the user (preferred — no sudo prompt), or
- `sudo mount`/`sudo umount` (acceptable, prompts for password).

The script should prefer `udisksctl` and fall back to sudo with a clear log line.

### 8.5 Out of scope

- Verifying firmware was actually loaded by reconnecting and reading `ready` (nice-to-have for v2.1).
- Cross-platform deploy (macOS/Windows). Linux only in v2.0.
- Versioning or rollback (the user can git-revert the firmware dir and re-deploy).

---

## 9. Serial Protocol Reference

This section is the canonical message catalogue. Both sides must implement exactly these.

### 9.1 Framing rules

- One JSON object per line, terminated by `\n` (LF, not CRLF).
- UTF-8.
- Max line length: 1024 bytes (enforced by both sides; over-length lines are dropped with an `error` reply).
- No comments, no trailing commas, no whitespace outside JSON tokens beyond the trailing `\n`.
- Order is preserved per direction (USB CDC is a stream).
- No request/response correlation IDs in v2.0 — all messages are fire-and-forget. (Add `id`/`reply_to` if needed in v2.1.)

### 9.2 Pico → Host messages

#### `ready`
Sent once on Pico boot, after asyncio main has started.
```json
{ "type": "ready", "protocol": 1, "app": "retro-deck", "buttons": 8, "display": { "w": 128, "h": 64 } }
```
Host responds with `hello`.

#### `tick`
Heartbeat every 5s. Host uses to detect a stalled firmware. **Stall threshold:** if the host receives no `tick` (and no other message) for 15s (3 missed ticks), it closes the port and re-enters the discovery/reconnect loop.
```json
{ "type": "tick", "t": 1234567 }
```

#### `button.press`
```json
{ "type": "button.press", "id": 1, "t": 12345 }
```

#### `button.hold`
Every 250ms while held, after the first 500ms of holding.
```json
{ "type": "button.hold", "id": 1, "t": 12895, "duration_ms": 550 }
```

#### `button.release`
```json
{ "type": "button.release", "id": 1, "t": 13100, "duration_ms": 755 }
```

#### `error`
Non-fatal firmware-side error.
```json
{ "type": "error", "code": "bad_keycode", "message": "unknown key 'FROBNICATE'", "context": { "button": 3 } }
```

#### `log`
Optional debug log line from firmware.
```json
{ "type": "log", "level": "info", "message": "binding set for button 5" }
```

### 9.3 Host → Pico messages

#### `hello`
Sent immediately after the host receives `ready` (and after reconnect). Acknowledges the device and resets the Pico's in-memory cache; host follows with state pushes.
```json
{ "type": "hello", "protocol": 1 }
```
The host owns all action and timing thresholds (long-press, etc.). The Pico does not need them — it streams raw events. `hello` carries no thresholds in v2.0.

#### `bind.set`
Set the keypress binding for one button. Repeated for every `keypress` button in the active profile.
```json
{ "type": "bind.set", "id": 2, "keys": ["CONTROL", "SHIFT", "R"] }
```
To clear a binding (button is `bash`/`function`/`noop`):
```json
{ "type": "bind.clear", "id": 2 }
```

#### `bind.clearAll`
Clear all keypress bindings. Sent at the start of a profile switch before re-issuing per-button binds.
```json
{ "type": "bind.clearAll" }
```

#### `display.layout`
Push the full body grid. Replaces any toast.
```json
{
  "type": "display.layout",
  "header": "OBS",
  "labels": ["black","soon","chat","edge","mic","video","t4w","mode"],
  "status": "● ready"
}
```

#### `display.toast`
Show a transient large message in the body area. Reverts to grid after `ttl_ms`.
```json
{ "type": "display.toast", "message": "✓ deploy", "ttl_ms": 1500 }
```

#### `display.status`
Update only the status line.
```json
{ "type": "display.status", "message": "● running…" }
```

#### `display.error`
Show an error banner over the body. Stays until cleared.
```json
{ "type": "display.error", "message": "config invalid" }
```

#### `display.clearError`
```json
{ "type": "display.clearError" }
```

#### `ping`
Health probe. Pico replies with a `pong`.
```json
{ "type": "ping", "n": 42 }
```
Reply (Pico → Host):
```json
{ "type": "pong", "n": 42, "t": 12345 }
```

### 9.4 Error handling

- **Malformed line** (host or device side): respond with `{"type":"error","code":"bad_json","message":"..."}` if possible; otherwise drop. Never crash the loop.
- **Unknown `type`:** respond with `{"type":"error","code":"unknown_type","message":"<the type>"}`.
- **Bad payload** (missing field, wrong type): respond with `{"type":"error","code":"bad_payload","message":"..."}`.
- **Resource unavailable** (e.g. binding requested before `hello`): respond with `{"type":"error","code":"not_ready"}`.
- All errors are logged on both sides.

### 9.5 Connect / reconnect dance

```
Pico boots → ready
                      ←───────  ready
            hello     ───────→
            bind.clearAll ───→
            bind.set …    ───→  (one per keypress button)
            display.layout  ─→
            display.status  ─→  (e.g. "● ready")
                              … steady state …
            ←─────  button.press
            ←─────  button.release
            display.toast  ─→  (action result)
                              …
Pico unplug → host sees EOF → backoff loop → re-detect → repeat from "ready"
```

---

## 10. Open Questions

These are deliberate gaps. Each one needs to be resolved by the issues writer or, where flagged, kicked back to the owner before implementation.

1. **Profile-switch button overload.** Long-press on the configured switch button cycles profiles; short-press fires its action. Is that ergonomic, or do we want to forbid configuring an action on the switch button to avoid confusion? **Recommend:** allow short-press action; document the overload clearly. Defer if ambiguous.

2. **`menu`-mode profile switching.** Spec'd above as v2.1. Does v2.0 need a fallback for users with >5 profiles who don't want to long-press 5 times? Possible v2.0 minimum: cycle only, but `POST /profiles/:name/activate` exists, so users with many profiles can wire a hotkey or the UI to switch.

3. **Webapp vs TUI for config UI.** PRD recommends webapp but acknowledges TUI is faster. **Owner decision needed before issue is written.** If TUI: drop the OLED-preview requirement.

4. **Daemon as systemd user service.** The PRD assumes the user will run the daemon as a long-lived service. Out of scope for the issues themselves, but the README needs to ship example unit files. **Owner decision: in v2.0 docs, or v2.1?**

5. **Multi-host / second Pico.** Not a goal, but if a second device is plugged in, the daemon should at least *not* connect to it and clobber the wrong device. **Recommend:** discovery uses a stable serial number from the Pico's USB descriptor; the host config can pin a specific serial. Defer to v2.1 unless the owner has two decks.

6. **Long-key-name truncation strategy.** `terminalio.FONT` is 6×8; in a 4×2 grid the per-cell label budget is ~10 chars. Truncate with `…` or scroll? **Recommend:** truncate in v2.0; vendor `adafruit_display_text` source for marquee scrolling in v2.1.

7. **Action concurrency model.** PRD says 1 action queued per button; further presses dropped. Is that the right policy? Alternative: cancel the in-flight action and start the new one. **Recommend:** queue=1, drop further; revisit if it's annoying in practice.

8. **Hot-reload of `function` modules.** If a `function` action's `.ts` file is edited, the import cache must be invalidated without a config-file change. Bun's `import()` caches by path. A `?t=<mtime>` query string trick on a file:// path is unreliable in Bun — the proper approach is a small wrapper that reads the source, evaluates it via a fresh worker, or uses `Bun.spawn` to run the module in a subprocess. **Recommend:** v2.0 watches action module files via `fs.watch`; on change, the wrapper drops its cached reference and re-imports the next time the action fires (acceptable cost: one stale execution if the press races the save).

9. **What happens on action timeout.** PRD says SIGTERM at 30s, SIGKILL 5s later. Should the OLED show a "killed" toast? **Recommend:** yes, `✗ timeout` toast.

10. **HID key release timing.** Pico sends keys on `press` and releases ~30ms later. Does any application need a longer hold (e.g. games)? **Recommend:** v2.0 fixed 30ms, configurable per-action in v2.1.

11. **Boot ordering.** If the daemon is up before the Pico is plugged in, is the "auto-discover with backoff" loop sufficient, or do we want udev rules to trigger discovery? **Recommend:** backoff is enough for v2.0; udev is a v2.1 polish.

12. **Error reporting on the OLED.** PRD says `display.error` banners stay until cleared. Should there be an auto-dismiss after N seconds? **Recommend:** auto-dismiss after `display.errorTtlMs` (default 5s) is the simpler default; daemon can re-send if the underlying state is still bad.

13. **Config schema versioning.** v2.0 hardcodes `version: 2`. Migration path for v2.1+ schema bumps not specified. **Defer:** add a migrator in v2.1 when the first incompatible change lands.

14. **Test strategy.** Not specified above. Suggested baseline:
    - Host: Bun's built-in test runner; mock the serial port with a virtual pty.
    - Firmware: hard to unit-test on Pico directly; instead, factor protocol parsing into a pure Python module testable on host CPython.
    - End-to-end: a "harness" config + a USB-attached Pico in CI. Out of scope for v2.0.

---

*End of PRD.*

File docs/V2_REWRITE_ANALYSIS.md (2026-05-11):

# Retro Deck — Current Implementation Analysis

> **Purpose:** Comprehensive snapshot of the V1 codebase for use by the V2 rewrite agent team.
> This document was produced by a coordinated 3-agent analysis. Sections are authored by:
> - **Coordinator** (Claude Sonnet 4.6) — Architecture, hardware, data model, OLED, file utilities
> - **Sonnet Agent** — Profile configs (all button mappings, HID keycodes)
> - **Opus Agent** — Library dependencies, gaps/TODOs, pain points, V2 constraints

---

## 1. Hardware

### Device
- **MCU**: Raspberry Pi Pico (RP2040, dual-core ARM Cortex-M0+)
- **Firmware runtime**: CircuitPython
- **Form factor**: 3D-printed 8-key macro pad with integrated OLED mount
- **Based on**: DaveM's [Stream Cheap](https://www.thingiverse.com/thing:2822140) design, adapted for Pico
- **3D files**: `prints/_v1/` and `prints/_v2/` (STL included: `Pico MacroPad + Oled.stl`)

### Bill of Materials
| Component | Notes |
|---|---|
| Raspberry Pi Pico | RP2040, not Pico W (no WiFi used) |
| 8x mechanical switches | MX-compatible |
| Keycaps | Standard MX |
| 0.96" SSD1306 OLED | 128×64px, I2C |
| Development breakout board | For wiring switches to GPIO |
| Threaded inserts + hex bolts | Enclosure fasteners |

### GPIO Pin Assignments

From `example-mappings.json` and `src/register_buttons.py`:

| Button # | GPIO Pin | Notes |
|---|---|---|
| 1 | GP20 | Pull-up, active low |
| 2 | GP19 | Pull-up, active low |
| 3 | GP18 | Pull-up, active low |
| 4 | GP17 | Pull-up, active low |
| 5 | GP11 | Pull-up, active low |
| 6 | GP12 | Pull-up, active low |
| 7 | GP13 | Pull-up, active low |
| 8 | GP14 | Pull-up, active low |

Default fallback pin range (no mappings.json): GP10–GP13, GP21–GP18 (reverse)

### OLED Wiring
| Signal | GPIO |
|---|---|
| SDA | GP0 |
| SCL | GP1 |
| Protocol | I2C, address 0x3C (60 decimal) |
| Driver | SSD1306 128×64 |

---

## 2. Firmware Architecture

### Entry Point: `code.py`

Startup sequence:
1. Import profile configs (`RiderConfig`, `DebugButtonFunctions`, `OBSConfig`)
2. Instantiate `Oled` → releases displays, sets up I2C, shows logo, goes to standby
3. Instantiate `Keyboard` (USB HID)
4. Instantiate all profile objects, pass `screen` + `kbd`
5. Load `mappings.json` if present, else use default pin order
6. Call `setup_buttons(button_map)` → returns list of 8 `DigitalInOut` objects
7. Set `current_config = configs[0].config` (Debug profile is always default)
8. Enter main loop

### Main Loop

```python
while not quit_app:
    for button in buttons:
        if not button.value:          # active low
            handle_button_press(button)
    time.sleep(0.01)                  # 10ms debounce tick
```

### Button Handler (`handle_button_press`)

- Determines key index (1-based) from `buttons.index(button)`
- Polls while button is held, incrementing `held_for` in 10ms ticks
- **Long press (>2s)**: switches active profile to `configs[key-1]` (button 1 → profile 0, etc.)
  - This means buttons 1–3 can switch profiles; buttons 4–8 cannot (only 3 profiles exist)
  - Displays profile name on OLED via `cfg.print_name(key)`
  - Consumes button release before returning
- **Short press**: looks up `current_config[key]["action"]` and calls `action(key)`

### Module Structure

```
code.py                        # entry point, main loop
src/
  buttons_functions.py         # (implied base — not present, each profile is standalone)
  debug_buttons_functions.py   # Debug profile
  obs_buttons.py               # OBS Studio profile
  rider_config.py              # JetBrains Rider profile
  webstorm_button_functions.py # JetBrains WebStorm profile (may be unused)
  oled.py                      # OLED display wrapper
  register_buttons.py          # GPIO button setup
  fileUtilities.py             # os.stat-based file existence check
lib/
  adafruit_hid/                # USB HID (keyboard, mouse, consumer control)
  adafruit_display_text/       # Text label rendering (compiled .mpy)
  adafruit_displayio_ssd1306.py # SSD1306 display driver
```

### Profile / Config System

Each profile is a class with:
- `mode: str` — display name
- `config: dict[int, {"name": str, "action": Callable}]` — keyed 1–8
- `print_name(name)` — shows selection on OLED
- Individual action methods (e.g. `start()`, `attach_debug()`)

Profile instances are stored in a `configs` list. Long-pressing button N switches to `configs[N-1]`.

---

## 3. Profile Configs

> **Authored by: Sonnet Agent** — fills this section with all button mappings, HID keycodes, timing details

<!-- SONNET_AGENT_START -->

### 3.1 Debug Profile (`src/debug_buttons_functions.py`)

| Button | Name | Keycodes | Delay after |
|---|---|---|---|
| 1 | BTN 1 | (none — echo/no-op) | — |
| 2 | BTN 2 | (none — echo/no-op) | — |
| 3 | BTN 3 | (none — echo/no-op) | — |
| 4 | BTN 4 | (none — echo/no-op) | — |
| 5 | BTN 5 | (none — echo/no-op) | — |
| 6 | BTN 6 | (none — echo/no-op) | — |
| 7 | BTN 7 | (none — echo/no-op) | — |
| 8 | BTN 8 | (none — echo/no-op) | — |

- All 8 buttons are wired to `self.print_name` — they only update the OLED with the button label and do nothing else.
- Five real action methods exist in the class but are **not wired into the config dict**:
  - `start_project`: no keycodes, `time.sleep(3)` — effectively a 3-second stall with OLED update only
  - `stop_project`: `CTRL+F2`, 1.5s delay
  - `previous_file`: `CTRL+SHIFT+TAB`, 0.3s delay
  - `next_file`: `CTRL+TAB`, 0.3s delay
  - `lock_screen`: `WINDOWS+L`, 1.5s delay
- The Debug profile is entirely a **placeholder** — it appears to be where new actions are developed before being promoted to a real profile.

### 3.2 OBS Profile (`src/obs_buttons.py`)

| Button | Name | Keycodes | Delay after |
|---|---|---|---|
| 1 | black | CTRL+ALT+SHIFT+1 | 1.5s |
| 2 | starting_soon | CTRL+ALT+SHIFT+2 | 1.5s |
| 3 | chatting | CTRL+ALT+SHIFT+3 | 1.5s |
| 4 | edge | CTRL+ALT+SHIFT+4 | 1.5s |
| 5 | mic_toggle | CTRL+ALT+SHIFT+5 | 1.5s |
| 6 | video_toggle | CTRL+ALT+SHIFT+6 | 1.5s |
| 7 | t4w | CTRL+ALT+SHIFT+7 | 1.5s |
| 8 | lofi | CTRL+ALT+SHIFT+8 | 1.5s |

- All keycodes use `Keycode.ONE` through `Keycode.EIGHT` (not numpad) with the `CTRL+ALT+SHIFT` modifier prefix — these are OBS scene-switching hotkeys.
- Copy-paste bugs: `mic_toggle` (button 5) and `lofi` (button 8) both call `self.print_name('edge')` instead of their own action names — the OLED label will show "edge" for those buttons.
- An `echo` lambda is defined in `__init__` but never used anywhere in the config.
- No conditional logic or branching in any action.

### 3.3 Rider Profile (`src/rider_config.py`)

Already read — documented here for completeness:

| Button | Name | Keycodes | Delay after |
|---|---|---|---|
| 1 | echo(1) — no-op label | (none) | — |
| 2 | start | CTRL+ALT+SHIFT+R | 1.5s |
| 3 | attach_debug | CTRL+ALT+F5 | 1.5s |
| 4 | stop_proj | SHIFT+F5 | 1.5s |
| 5–8 | echo(N) — no-op label | (none) | — |

### 3.4 WebStorm Profile (`src/webstorm_button_functions.py`)

**This file is a stub — no class, no config, no button mappings exist.**

The file contains only a 4-line comment block:
```python
###
# Webstorm buttons functions
# Methods for the debug profile of the RetroDeck
###
```

- No `class`, no `config` dict, no action methods defined.
- The profile is listed as a `# TODO` in `code.py` (`# TODO: - Profile for Webstorm actions`) confirming it was never implemented.
- The file is not imported in `code.py` and has no effect at runtime.

<!-- SONNET_AGENT_END -->

---

## 4. OLED Display System (`src/oled.py`)

### Hardware Init
- Releases all `displayio` displays on startup (required by CircuitPython for re-init)
- I2C on GP0/GP1, locked/unlocked before display init
- 50ms settle delay after display bus creation
- Shows logo scene briefly on startup

### Scenes

| Method | Content | When Used |
|---|---|---|
| `set_logo()` | "RetroDeck" centered, scale=2 | On boot, 300ms |
| `set_standby()` | Line 1: "RetroDeck v1.0.0" · Line 2: "MODE: STANDBY" | After boot, on profile switch |
| `set_confirm_selection(mode, name)` | Line 1: app name+version · Line 2: "Mode: {mode}" · Line 3: selection name (scale=2, uppercase) | After button press action |

### Display Pattern
- `current_scene` group is tracked; `.pop()` removes previous content before drawing new scene
- All scenes use `terminalio.FONT` (built-in monospace bitmap font)
- No animation, no brightness control, no sleep/wake

---

## 5. Configuration / Data Model

### `mappings.json` Schema

```json
{
  "mappings": [
    { "Pin": 20, "Button": 1 },
    { "Pin": 19, "Button": 2 },
    ...
  ]
}
```

- Loaded at startup if file exists (`file_exists('mappings.json')`)
- Parsed once; used to order `buttons[]` list by button number
- If absent: default GPIO sequence is used (hardcoded in `register_buttons.py`)
- No hot-reload; change requires device reset

### Config Object Shape (per profile)

```python
{
  1: { "name": "action_name", "action": callable },
  2: { "name": "action_name", "action": callable },
  ...
  8: { "name": "action_name", "action": callable },
}
```

- Keys are `int` 1–8
- `action` is a bound method — receives `button_index: int` as argument
- No persistence of which profile is active between resets (always boots to `configs[0]`)

### File Utilities (`src/fileUtilities.py`)

```python
def file_exists(filename: str) -> bool:
    # uses os.stat() — OSError means file absent
```

Only used to check for `mappings.json`. No other file I/O at runtime.

---

## 6. Library Dependencies

> **Authored by: Opus Agent** — fills this section

<!-- OPUS_AGENT_START -->

### 6.1 Bundled vendor libraries (`lib/`)

| Library | Version | Form | Source |
|---|---|---|---|
| `adafruit_hid` | 5.3.0 | bundled `.py` (editable) | [Adafruit_CircuitPython_HID](https://github.com/adafruit/Adafruit_CircuitPython_HID) |
| `adafruit_displayio_ssd1306` | 1.5.6 | bundled `.py` (editable) | [Adafruit_CircuitPython_DisplayIO_SSD1306](https://github.com/adafruit/Adafruit_CircuitPython_DisplayIO_SSD1306) |
| `adafruit_display_text` | unknown (mpy header) | compiled `.mpy` (read-only) | [Adafruit_CircuitPython_Display_Text](https://github.com/adafruit/Adafruit_CircuitPython_Display_Text) |

#### `adafruit_hid` — USB HID device drivers
Provides keyboard, mouse, and consumer-control HID report senders that target a `usb_hid.Device`.

| Sub-module | What it provides | Used by V1? |
|---|---|---|
| `__init__.py` | `find_device(devices, usage_page, usage)` helper | indirectly (via `Keyboard`) |
| `keyboard.py` | `Keyboard` class — `press()`, `release()`, `release_all()`, `send(*keycodes)` | **YES** — `Keyboard(usb_hid.devices)` + `kbd.send(...)` only |
| `keycode.py` | `Keycode` class — named USB HID usage codes (A–Z, F1–F24, modifiers, ONE–ZERO, TAB, etc.) | **YES** — `CONTROL, ALT, SHIFT, WINDOWS, F2, F5, TAB, R, L, ONE..EIGHT` |
| `consumer_control.py` | `ConsumerControl` class — media/volume/brightness reports | **No** (bundled but unused) |
| `consumer_control_code.py` | `ConsumerControlCode` enum (VOLUME_INCREMENT, SCAN_NEXT_TRACK, …) | **No** |
| `keyboard_layout_us.py` | `KeyboardLayoutUS` — string-to-keypress translation | **No** |
| `keyboard_layout_base.py` | `KeyboardLayoutBase` (parent) | **No** |
| `mouse.py` | `Mouse` class — `press()`, `release()`, `click()`, `move()` | **No** |

#### `adafruit_displayio_ssd1306` — SSD1306 OLED driver
Single-class module exposing `SSD1306(displayio.Display)`. Used by `src/oled.py` to wrap the I2C bus and drive the 128×64 panel. Editable, so tweaking init sequence / contrast / inversion is in-scope.

#### `adafruit_display_text` — bitmap text rendering
Provides `label.Label`, `bitmap_label.Label`, `scrolling_label.ScrollingLabel`. **All sub-modules are pre-compiled `.mpy`** — to modify rendering behaviour V2 must replace the whole package with a `.py` source build (or hand-roll the text routine). V1 uses only `from adafruit_display_text import label` → `label.Label(font, text, x, y, scale)`.

### 6.2 CircuitPython built-in modules

These ship with the CircuitPython firmware itself (no files in `lib/`) and are immutable from the device side.

| Module | Used in V1 by | Surface used |
|---|---|---|
| `board` | `oled.py`, `register_buttons.py` | `board.GP0`, `board.GP1`, `getattr(board, 'GP{n}')` for `n ∈ {10..14, 17..21}` |
| `busio` | `oled.py` | `busio.I2C(SCL, SDA)`, `try_lock()`, `unlock()` |
| `displayio` | `oled.py` | `release_displays()`, `Group()`, `I2CDisplay(bus, device_address=60)` |
| `terminalio` | `oled.py` | `terminalio.FONT` (built-in 6×8 monospace bitmap) |
| `digitalio` | `register_buttons.py` | `DigitalInOut`, `Direction.INPUT`, `Pull.UP` |
| `usb_hid` | `code.py` | `usb_hid.devices` (sequence passed to `Keyboard`) |
| `micropython` | `adafruit_hid/keyboard.py` (vendored) | `const()` |
| `time` | `code.py`, all profiles, `oled.py` | `time.sleep()` only |
| `json` | `register_buttons.py`, `fileUtilities.py` (imported but unused there) | `json.loads()` |
| `os` | `fileUtilities.py` | `os.stat()` |

**Not yet used but available in stock CircuitPython** (V2 will rely on these):
- `usb_cdc` — USB serial port (the missing host channel — see §7)
- `supervisor` — soft reload, runtime status, `ticks_ms` timer
- `microcontroller` — NVM byte storage for persistent profile-index across reboots
- `storage` — remount CIRCUITPY read-write from the device side (needed if firmware itself wants to write config)
- `asyncio` (CircuitPython 8+) — non-blocking concurrent button + serial loops

### 6.3 V2 retention vs. replacement

**Must keep (no realistic alternative on this MCU):**
- `board`, `busio`, `digitalio`, `displayio`, `terminalio`, `usb_hid`, `usb_cdc` — the CircuitPython HAL.
- `adafruit_displayio_ssd1306` — the only sane SSD1306 driver for `displayio`.
- `adafruit_hid.keyboard.Keyboard` + `Keycode` — needed for any keypress-type action the Pico itself emits.

**Keep but extend:**
- `adafruit_display_text` — currently `.mpy` only. Either accept the limitation, or vendor the source `.py` build to gain custom rendering (icons, inverted regions, marquee labels for long button names).
- `adafruit_hid.mouse.Mouse` and `consumer_control` — already bundled; cheap to expose as additional V2 action types (`mouse-click`, `media-key`).

**Replace / add:**
- Replace the hand-rolled long-press scan loop in `code.py` with non-blocking event detection (e.g. `keypad.Keys` from CircuitPython core, or an `asyncio` loop).
- Add a `usb_cdc.data` JSON-line protocol layer — the central new piece.
- Add a small persistence layer (`microcontroller.nvm` or a JSON file written via CDC handshake) for last-active profile index.

<!-- OPUS_AGENT_END -->

---

## 7. Gaps, TODOs, and Pain Points

> **Authored by: Opus Agent** — fills this section

<!-- OPUS_AGENT_START_2 -->

### 7.1 TODO inventory

A `grep -rn 'TODO\|FIXME\|XXX\|HACK'` over the whole repo (`code.py`, `src/`, `README.md`) returns exactly five hits, all clustered at the top of `code.py`:

| File:Line | TODO |
|---|---|
| `code.py:11` | `# TODO: - Switch profile button` |
| `code.py:12` | `# TODO: - Companion App - Open specific apps` |
| `code.py:13` | `# TODO: - Profile for Launcher - Open specific apps` |
| `code.py:14` | `# TODO: - Profile for HomeKit actions` |
| `code.py:15` | `# TODO: - Profile for Webstorm actions` |

All five point at the same root issue: there is no way for the Pico to do anything except press hardcoded keystrokes, so every "feature idea" stalls at "we'd need a different architecture."

The README adds an informal self-assessment: *"Your code is shit." — "I know. I'm working on it."*

### 7.2 Latent bugs and dead code

| # | File:Line | Issue |
|---|---|---|
| B1 | `code.py:67-68` | `if configs[index]:` indexes `configs[]` directly with `key-1`. There are only 3 entries (Debug, Rider, OBS) but 8 buttons — long-pressing buttons 4–8 raises `IndexError` and crashes the firmware (CircuitPython drops to REPL). |
| B2 | `code.py:43` | `current_config = configs[0].config` — boot always starts in Debug, regardless of last user choice. There is no persistence (no `microcontroller.nvm`, no file write). |
| B3 | `code.py:74-76` | After the long-press fires, the inner `while not button.value` busy-loops at 10 ms with no timeout, blocking everything else (other buttons, screen updates). Stuck-key = stuck firmware. |
| B4 | `code.py:90-95` | Main loop is single-threaded blocking. While a profile method calls `time.sleep(1.5)` (every short-press in OBS/Rider/Debug.stop), no other button can register, and the OLED can't update. |
| B5 | `src/register_buttons.py:28` | `buttons.insert(val["Button"] - 1, …)` does **not** guarantee positional ordering if mappings are out-of-order or skip indices — it inserts, doesn't pad. A `mappings.json` listing buttons `[3,1,2,…]` produces a wrong-order list with no error. |
| B6 | `src/register_buttons.py:17-20` | Default fallback range hardcodes `GP10..GP13` then `GP21..GP18` (reverse). Doesn't match the documented production wiring (`GP20..GP17, GP11..GP14` per `example-mappings.json`) — anyone running without a mappings file gets a layout that doesn't match the case. |
| B7 | `src/webstorm_button_functions.py` | File exists and is a 4-line comment header. No class, no config, never imported in `code.py`. Dead reference. |
| B8 | `src/fileUtilities.py:1` | `import json` is imported but never used in this file. |
| B9 | `src/debug_buttons_functions.py:19-21` | `start_project` exists but is **not wired into `self.config`** — the Debug profile maps every button (1–8) to `print_name` only. `stop_project`, `previous_file`, `next_file`, `lock_screen` are similarly defined but unreachable. |
| B10 | `src/oled.py:30` | `print()` with no argument inside the I2C init — leftover debug noise. |
| B11 | `src/oled.py:33` | `device_address=60` (decimal `0x3C`) is hardcoded — no fallback for SSD1306 modules wired to `0x3D`. |
| B12 | `code.py:56` | `quit_app = False` / `config_mode = False` are declared but never reassigned anywhere — `while not quit_app` is a permanent `while True`. |

### 7.3 Architectural limitations

V1 is a **pure HID emitter with no return channel.** Everything that follows stems from that.

1. **No USB CDC / serial comms.** `boot.py` doesn't enable `usb_cdc.data`, and nothing in `code.py` reads or writes a serial port. The Pico has zero ability to tell the host what just happened, and the host has zero ability to tell the Pico what to do.
2. **No host → device channel.** The host cannot push display content, button labels, profile changes, or status. Every byte the Pico emits is a synthetic keystroke.
3. **No event acknowledgement.** When a button is pressed and a keystroke is sent, there is no signal that the host received it, processed it, or rejected it. Fire-and-forget.
4. **No structured data channel.** All "communication" is a hardcoded macro pretending to be a keyboard. No JSON, no framed messages, no IDs.
5. **No dynamic config.** `mappings.json` is read once at boot. Changing a mapping requires editing the file and resetting the Pico. Profile contents (which keystroke maps to which button) are baked into Python class bodies and require a code edit + reset.
6. **No hot-reload of profiles.** CircuitPython auto-reloads on `code.py` save, but profile files live under `src/` and changes there don't always trigger a reload reliably; even when they do, every reset wipes the in-memory active-profile selection.
7. **No persistent state.** Active profile, last action, and any kind of usage counter are all in RAM. Reboot → back to Debug.
8. **No key labelling mechanism.** Names exist only inside the per-profile `config` dict and surface only after a button is pressed (`set_confirm_selection`). The user has no way to know what each key currently does without pressing it.
9. **Profile-switching gesture is broken.** Long-press on button N selects `configs[N-1]`. Buttons 1–3 work. Buttons 4–8 long-press → `IndexError` (B1). There is no dedicated profile-cycle key, no on-screen menu, no host-driven switch.
10. **Blocking main loop.** Every action ends in `time.sleep(1.5)` inside a single-threaded loop. No concurrent input, no animated display, no asynchronous host comms — adding any of those requires reworking the loop entirely.
11. **No mouse / consumer-control bindings.** `adafruit_hid.mouse` and `adafruit_hid.consumer_control` are bundled but unused. V1 is keyboard-only.
12. **No identity / pairing.** Nothing distinguishes one Retro Deck from another at the USB layer beyond a stock CircuitPython VID/PID. The host can't address a specific device.
13. **No timing source for events.** `time.sleep()` is the only `time` API used. There is no `ticks_ms` event timestamping — `held_for` is a counter, not a timestamp.
14. **No error reporting.** Exceptions drop the firmware into the CircuitPython REPL with no visual or audible hint to the user.

### 7.4 UX limitations

- **Long-press-only profile switching** — there's no dedicated button, no menu, no shortcut. Mode change is invisible until it happens.
- **Three profiles, eight buttons** — buttons 4–8 long-press crash the firmware (B1), so the gesture is half-broken even within its own design.
- **No on-screen indication of current profile** — between actions the OLED shows `MODE: STANDBY` after a profile switch via `set_standby()`? No — actually `set_standby()` is only called once at boot. After a profile switch the screen stays on `set_confirm_selection` forever, until the next press. There is no persistent header showing "you are in OBS profile."
- **No indication of which buttons are active vs no-op** — Rider has 4 active buttons, 4 echoes; Debug is 8 echoes; nothing on screen tells the user that.
- **Physical keycaps are unlabelled** — same blank caps regardless of profile. No legend sheet, no LCD-per-key, no host-pushed icon.
- **Action confirmation overwrites itself** — every press wipes the previous label; you can't see a recent action history.
- **No volume/brightness/sleep affordance for the OLED** — it's always at full brightness, always on.
- **Boot logo is a 300 ms flash** that disappears before the user can read it.
- **No haptic / audible feedback** — only visual via OLED.

### 7.5 What V1 cannot do that an agent-driven V2 needs

An "agent-driven" Retro Deck means: a host process (Claude Code, a TUI, a daemon) treats the device as a peripheral with two-way structured comms, and uses it to surface state, request approval, and run arbitrary host-side actions. V1 is incapable of *every* requirement on that list:

| Capability V2 needs | V1 gap |
|---|---|
| Host pushes a button label set | No host→device channel |
| Host pushes display content (current profile, agent state, prompts) | OLED is driven only by local profile classes |
| Host receives button events with IDs and timestamps | No outbound channel except synthetic keystrokes |
| Host distinguishes press / release / hold / double-tap | V1 collapses everything to "press fires action" or "hold ≥2s switches profile" |
| Host remaps buttons at runtime | Profiles are Python classes; remap requires file edit + reset |
| Host runs arbitrary shell / TS code in response to a press | Pico can only synthesize keystrokes |
| Approval workflow (button = "approve" / "deny" with confirmation) | No way to send "the user pressed approve" as a structured message |
| Persistent active-profile across reboots | Always boots to `configs[0]` |
| Multiple named profiles (more than 3) selectable from host | Profile list is a 3-element Python list with broken long-press selection |
| Per-button icon / glyph rendering on display | OLED only renders text labels with `terminalio.FONT` |
| Device identity / multi-device disambiguation | No identity beyond stock USB descriptors |
| Firmware self-report ("ready", "busy", "error") | No protocol layer at all |
| Graceful error surfacing | Unhandled exceptions drop to REPL silently |
| Config UI for non-engineers | Editing `mappings.json` + Python files on a CIRCUITPY mount is the entire workflow |

### 7.6 README self-assessment

> *"Your code is shit." — "I know. I'm working on it."*  — `README.md`

<!-- OPUS_AGENT_END_2 -->

---

## 8. V2 Rewrite Constraints and Context

### Fixed Hardware Constraints (cannot change without new hardware)
- Raspberry Pi Pico (RP2040) — CircuitPython only (no MicroPython or bare-metal assumed)
- 8 mechanical switches on fixed GPIO pins (remappable via config, but count is fixed)
- SSD1306 128×64 OLED on I2C GP0/GP1
- USB connection to host (USB HID + USB CDC available in CircuitPython)
- No WiFi (Pico, not Pico W) — all host comms must be USB

### What V2 Must Solve
1. **Host communication** — Pico must send events to and receive commands from a host process
2. **Dynamic config** — button mappings controlled by host at runtime, not baked into firmware
3. **Action execution on host** — bash commands and TypeScript functions run on host, not Pico
4. **Configuration UI** — a TUI, webapp, or desktop app to edit all configs and see all 8 slots per profile
5. **Mode/profile system** — infinite named profiles, toggle via dedicated button or external trigger
6. **Display driven by host** — host pushes what to show on OLED (current profile name, button labels, agent state)
7. **Deploy tooling** — `/dev/sda1` (CIRCUITPY volume) needs a mount/rsync/unmount script for iteration

### What V1 Got Right (keep in V2)
- Physical 8-key layout with long-press profile switching is intuitive
- `mappings.json` for GPIO remapping is a good pattern — extend it
- OLED feedback on action is useful — expand it
- CircuitPython is the right choice for approachability and iteration speed

### V2 Action Type Model (proposed)
```typescript
type Action =
  | { type: "keypress"; key: string }          // Pico sends HID directly
  | { type: "bash"; cmd: string }              // Host daemon executes
  | { type: "function"; module: string }       // Host daemon imports + runs
```

### V2 Communication Protocol (proposed)
- **Transport**: USB CDC serial (`/dev/ttyACM1`) — JSON lines, newline-delimited
- **Pico → Host**: `{"type":"button","id":1,"event":"press"}` / `{"type":"button","id":2,"event":"hold","duration":2.3}`
- **Host → Pico**: `{"type":"display","title":"Dev Mode","hint":"1=tests 8=stop"}` / `{"type":"labels","buttons":{"1":"run","8":"deny"}}`
- **Pico → Host** on boot: `{"type":"ready","buttons":8,"display":true}`

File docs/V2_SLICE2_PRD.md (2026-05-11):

# Retro Deck V2 — Slice 2 PRD

> **Status:** Implementation-ready
> **Audience:** Two implementation agents (frontend + backend)
> **Owner:** rld
> **Coordinator:** Opus (this conversation)

This slice closes the "edit binding → press button → action fires" loop. It does not yet move toward the full V2 PRD schema (`device`/`display`/`http`/`version`/`function`); that's Slice 3.

## Current state (as committed on `feature/v2-rewrite`)

- **Server schema** (authoritative for this slice): `host/src/server/config.ts`
  ```ts
  Action =
    | { type: 'bash';     label?: string; cmd: string }
    | { type: 'keypress'; label?: string; keys: string[] }
    | { type: 'profile';  label?: string; profile: string }
    | { type: 'noop';     label?: string }

  ButtonBinding = { press?: Action; hold?: Action; color?: string; icon?: string }
  Profile       = { name: string; buttons: Record<string, RawButton> }
  Config        = { activeProfile: string; profiles: Record<string, Profile> }
  ```
  `RawButton = Action | ButtonBinding` — both shapes accepted; `normalizeBinding()` collapses to `ButtonBinding`.

- **Dispatch** (`host/src/server/dispatch.ts`) — `bash` works, `profile` works, `noop` works, **`keypress` is a `console.log` stub**.

- **API** (`host/src/server/api.ts`): `GET /api/status`, `GET/PUT /api/config`, `POST /api/profile/:name`, `POST /api/fire/:id/:slot`, `GET /api/events` (SSE).

- **UI** (`host/src/client/*`): profile pills + 4×2 button grid (read-only) + Test button per card + live event log.

## Two epics in this slice

### Epic A — Inline Binding Editor (frontend only)
Make the grid editable. Click a card → drawer with a form per action type. Save → `PUT /api/config` → daemon hot-reloads.

### Epic B — Keypress Action Execution (backend only)
Implement the `keypress` branch in `dispatch.ts` so a bound keypress action actually emits the keystroke on the host using `ydotool`.

**Files touched by Epic A are disjoint from Epic B — they run in parallel.**

---

## Epic A — Binding Editor

### Goal
A user clicks any `ButtonCard`, picks an action type, fills the fields, saves, and the daemon immediately hot-reloads with the new binding. The card reflects the change without a manual reload.

### Files this epic owns (create or modify)
- `host/src/client/components/BindingDrawer.tsx` — new, the drawer shell + tabs/segmented control for action type
- `host/src/client/components/forms/BashForm.tsx` — new
- `host/src/client/components/forms/KeypressForm.tsx` — new
- `host/src/client/components/forms/ProfileForm.tsx` — new
- `host/src/client/components/forms/NoopForm.tsx` — new (just a placeholder body)
- `host/src/client/components/ButtonCard.tsx` — make the whole card a clickable open-drawer target; the **Test** button stays and stops propagation so clicking it doesn't open the drawer
- `host/src/client/components/ButtonGrid.tsx` — owns the drawer-open state (which button id is being edited)
- `host/src/client/queries/config.ts` — add `useSaveBinding({ profileName, id, binding })` mutation that does `PUT /api/config` with the next full Config
- `host/src/client/lib/binding.ts` — add `setBinding(config, profileName, id, binding)` pure helper
- `host/src/client/styles.css` — drawer + form styles

**Do NOT modify:** anything under `host/src/server/`, `host/server.ts`, any other server-side file, `App.tsx`.

### Behavior spec

1. **Open**: clicking the card body (not the Test button) opens the drawer for that button id. Only one drawer open at a time.
2. **Action type tabs**: a 4-way segmented control: Bash · Keypress · Profile · Noop. Switching tabs reshapes the form. Switching to a new type with no data resets to that type's default empty value.
3. **Form per type**:
   - **Bash**: `<label>` text input + `<cmd>` textarea (single-line ok; allow multi-line). Validation: cmd non-empty.
   - **Keypress**: `<label>` text input + a key-combo capture area. Capture works by clicking "Capture" then pressing the desired combo on the keyboard; show the captured combo as token chips (`Ctrl + Shift + R`). Allow manual edit by clearing + retyping a `+`-joined string. Store as `keys: string[]` lowercased per the host alias table in `V2_PRD.md` §6.4.1 (but for this slice, **store whatever the user typed**, lowercased — alias mapping is Slice 3). Validation: ≥1 token.
   - **Profile**: `<label>` text input + a `<select>` of all profile names from the current config. Validation: profile must exist.
   - **Noop**: just `<label>` input. No other fields.
4. **Slot**: this slice edits the `press` slot only. (Hold slot deferred — leave the binding's `hold` field unchanged if present.)
5. **Save**: builds the next `Config` by replacing `profiles[activeProfile].buttons[id]` with a `ButtonBinding` whose `press` is the new action. Calls `PUT /api/config`. On success: close drawer, invalidate `['config']` and `['status']`. On error: show error inline, leave drawer open.
6. **Cancel / Esc / click outside**: closes the drawer without saving.
7. **Loading/pending states**: save button shows "Saving…" while pending and is disabled. Form inputs disabled during save.

### Non-functional
- Keyboard accessible: Esc to close, Enter inside text inputs doesn't submit accidentally — there must be an explicit Save button.
- The drawer is a right-side panel on desktop, full-screen modal on mobile (CSS media query).
- No new dependencies. React + existing Tanstack Query + plain CSS only.

### Test plan (manual, for the agent to walk through before reporting done)
1. Start the daemon with `bun host/scripts/daemon-ctl.ts status` — should be running.
2. Open `http://localhost:7842/`.
3. Click button #1 → drawer opens.
4. Switch to Keypress tab → click Capture → press `Ctrl+Shift+R` → see chips → Save.
5. Card #1 should show type=KEYPRESS, summary `ctrl + shift + r`.
6. Reload the page → state persists (config file was written).
7. Click #2 → Bash → set cmd `notify-send hello` → Save → Test button fires the notify.
8. Click #3 → Profile → pick another profile (if more than one exists) → Save → card summary shows `→ <name>`.
9. Esc closes without saving; click-outside closes without saving.

### Done = report this back to the coordinator
- Files changed (list).
- `bun run typecheck` clean output.
- Confirmation that the 9 test-plan steps all pass.
- Any surprises or judgment calls made.

**Do NOT** start Epic B work. **Do NOT** touch server files. **Do NOT** modify the action schema in `config.ts`. **Do NOT** add new npm dependencies. If something blocks you, stop and message the coordinator.

---

## Epic B — Keypress Action Execution

### Goal
When a `keypress` action fires (either from a physical button press or a Test fire), the configured keystroke is actually emitted on the host.

### Host capability (confirmed by coordinator)
- `/usr/bin/ydotool` is installed.
- The `ydotool` systemd user service is **active**; socket at `$XDG_RUNTIME_DIR/.ydotool_socket` (or wherever the user service places it — `ydotool` reads `YDOTOOL_SOCKET` env or default).
- `/dev/uinput` exists, current user is in `input` group.
- Wayland (Hyprland) — `wtype` is also installed as a fallback, but **prefer ydotool** (works under Hyprland focused windows; wtype has compositor quirks).

### Files this epic owns (create or modify)
- `host/src/server/dispatch.ts` — implement the `keypress` branch.
- `host/src/server/keymap.ts` — new. Maps human-friendly tokens (the `keys: string[]` array from config) to ydotool keycodes.
- (Optional, only if needed) `host/scripts/keymap-dump.ts` — utility script that prints the keymap for diagnosis.

**Do NOT modify:** any UI file, any other server file, the action schema in `config.ts`. **Do NOT** change the wire shape of `Action.keypress`.

### Behavior spec

1. **Input shape**: `Action.keypress.keys: string[]` — each string is one token like `"ctrl"`, `"shift"`, `"r"`, `"f5"`, `"enter"`. Case-insensitive.
2. **Mapping**: lowercase each token, look up in the alias table (see below). Unknown tokens cause the dispatch to log an error and emit nothing.
3. **Emission**: use `ydotool key` with hold-then-release notation: `<KEYCODE>:1` to press, `<KEYCODE>:0` to release. Press modifiers first → press main key(s) → release all in reverse order. Example for `ctrl+shift+r`:
   ```
   ydotool key 29:1 42:1 19:1 19:0 42:0 29:0
   ```
   (29 = LEFT_CTRL, 42 = LEFT_SHIFT, 19 = R — Linux input event codes from `linux/input-event-codes.h`.)
4. **Hold timing**: 30ms between full press and full release. Use a single `ydotool key` invocation with sleep tokens (`-d 30` or chained `:1 -d 30 :0`) per ydotool man page — or, if simpler, spawn ydotool, sleep 30ms in TS, then a second ydotool for release. Single-invocation is preferred (less latency, one process).
5. **Process spawn**: `Bun.spawn(['ydotool', 'key', ...args], { stdout: 'pipe', stderr: 'pipe' })`. Await exit; on non-zero, log stderr.
6. **Environment**: read `YDOTOOL_SOCKET` if set; otherwise let ydotool default. Do not assume the socket path.
7. **No state**: dispatch is fire-and-forget. Don't queue. Don't retry.

### Keymap (use Linux input event codes — these are the integers ydotool expects)

Implement at least these. Anything not in the table → log error and emit nothing.

| Token (lowercased) | Code | Notes |
|---|---|---|
| `ctrl`, `control` | 29 | LEFTCTRL |
| `shift` | 42 | LEFTSHIFT |
| `alt`, `option`, `opt` | 56 | LEFTALT |
| `super`, `cmd`, `meta`, `win`, `windows` | 125 | LEFTMETA |
| `a` | 30 | … (alphabet a–z = 30..44 wrapping, see table) |
| `b` | 48 |
| `c` | 46 |
| `d` | 32 |
| `e` | 18 |
| `f` | 33 |
| `g` | 34 |
| `h` | 35 |
| `i` | 23 |
| `j` | 36 |
| `k` | 37 |
| `l` | 38 |
| `m` | 50 |
| `n` | 49 |
| `o` | 24 |
| `p` | 25 |
| `q` | 16 |
| `r` | 19 |
| `s` | 31 |
| `t` | 20 |
| `u` | 22 |
| `v` | 47 |
| `w` | 17 |
| `x` | 45 |
| `y` | 21 |
| `z` | 44 |
| `1`..`9`, `0` | 2..10, 11 |
| `enter`, `return` | 28 |
| `esc`, `escape` | 1 |
| `tab` | 15 |
| `space`, `spacebar` | 57 |
| `backspace` | 14 |
| `delete`, `del` | 111 |
| `home` / `end` | 102 / 107 |
| `pageup` / `pagedown` | 104 / 109 |
| `left` / `right` / `up` / `down` | 105 / 106 / 103 / 108 |
| `f1`..`f12` | 59..70 |
| `minus`, `-` | 12 |
| `equals`, `=` | 13 |
| `,` | 51 |
| `.` | 52 |
| `/` | 53 |
| `;` | 39 |
| `'` | 40 |
| `[` | 26 |
| `]` | 27 |
| `\\` | 43 |
| `` ` `` | 41 |

These codes come from `linux/input-event-codes.h` (`KEY_*` constants). Trust them; do **not** spend time researching.

### Test plan (manual, for the agent to walk through before reporting done)
1. Edit `~/.config/retro-deck/config.json` to give button 1 a `keypress` action with `keys: ["ctrl", "alt", "t"]`. (Or use the Test endpoint — see step 3.)
2. Daemon should hot-reload; coordinator-built UI may show the change.
3. From a terminal: `curl -X POST http://localhost:7842/api/fire/1/press`.
4. Observe: on Omarchy/Hyprland, `Ctrl+Alt+T` opens a terminal. Confirm a new terminal opened.
5. Try a single character: `keys: ["a"]` → fire → an `a` is typed into whichever window is focused.
6. Try an unknown token: `keys: ["frobnicate"]` → fire → daemon log shows an error, nothing emitted, no crash.
7. Run `bun run typecheck` — clean.

### Done = report this back to the coordinator
- Files changed (list).
- `bun run typecheck` clean.
- Confirmation that the 7 test-plan steps all pass (the agent will need a way to test — `curl` is fine; visual confirmation of the terminal opening is acceptable).
- Any surprises (e.g., if ydotoold socket needs explicit env, note it).

**Do NOT** start Epic A work. **Do NOT** touch UI files. **Do NOT** change the config schema. If the keymap codes seem wrong, **fix them locally** — don't go research the kernel headers, the codes above are correct.

---

## Coordination rules

1. Each agent does ONLY its assigned epic. Nothing else.
2. No new dependencies. No `bun add`.
3. No refactors outside scope. No "while I was here" cleanups.
4. When done, post the report described under "Done = report this back" and STOP. Do not move on. Wait for the coordinator.
5. If blocked, message the coordinator (named `coordinator` in the team) with a clear description of what's blocking. Do not improvise.
6. `host/src/server/serial.ts` is fragile — leave it alone.
7. The daemon is currently running on port 7842 via `bun host/scripts/daemon-ctl.ts`. To pick up server-side changes, the agent assigned Epic B must `bun host/scripts/daemon-ctl.ts restart` after editing. Frontend (Epic A) is HMR-live — no restart needed.

---

*End of Slice 2 PRD.*

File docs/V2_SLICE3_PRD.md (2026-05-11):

# Retro Deck V2 — Slice 3 PRD

> **Status:** Implementation-ready
> **Audience:** Two implementation agents (`backend`, `frontend`)
> **Owner:** rld
> **Coordinator:** Opus (this conversation)
> **Builds on:** `V2_SLICE2_PRD.md` (binding editor + keypress dispatch)

This slice rounds out the control surface:

1. Every action emits a result event the UI can react to (success/fail/stderr).
2. Users can create, rename, and delete profiles from the UI.

It does **not** yet touch the full V2 PRD schema migration, the `function` action type, the hold-slot editor, or OLED-push. Those are future slices.

## Two epics in this slice

### Epic C — Action results + profile CRUD (backend only)
Make dispatch emit a structured `action.result` event after each action runs, and expose `POST /api/profiles`, `PUT /api/profiles/:name`, `DELETE /api/profiles/:name` for profile management.

### Epic D — Profile management UI + result toasts (frontend only)
Add profile-row controls (➕ add, kebab → rename / delete) and a toast layer that subscribes to `action.result` events and renders transient success/error cards.

**File sets are disjoint — these run in parallel.**

---

## Epic C — Backend

### Goal

Two outcomes:

1. After any action fires (whether by physical button press or via `POST /api/fire/:id/:slot`), the daemon emits a single `action.result` event over the existing SSE stream describing what happened.
2. Three new API endpoints let the UI add / rename / delete profiles. The daemon persists changes through the existing `saveConfig` path, which already triggers the file watcher and hot-reload.

### Files this epic owns (create or modify)

- `host/src/server/dispatch.ts` — emit `action.result` after each branch resolves. Signature changes to accept the slot name so the event can include it.
- `host/src/server/api.ts` — add 3 new routes; update the existing `/api/fire/:id/:slot` to pass `slot` through to `dispatch`.
- `host/src/server/config.ts` — add `createProfile(name)`, `renameProfile(from, to)`, `deleteProfile(name)` helpers. Use the existing `saveConfig` so behavior matches the file-watcher path.
- `host/src/server/events.ts` — no changes expected. Re-use `emit()`.
- `host/server.ts` — update the `startSerial` callback to pass `'press'` (and `'hold'` when relevant) to `dispatch`. **Do not change anything else in this file.**

**Do NOT modify:** anything under `host/src/client/`, `host/src/server/serial.ts`, `host/src/server/keymap.ts`, `host/scripts/*`, or the schema in `config.ts` (the action types stay exactly as-is).
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

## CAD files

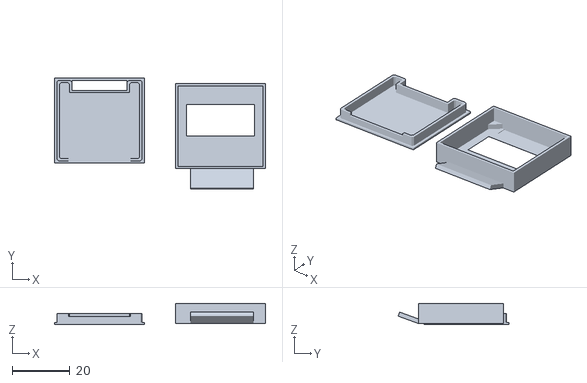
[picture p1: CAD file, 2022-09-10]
prints/_v2/Angled OLED Mount.stl
73.4 x 38.5 x 7.36

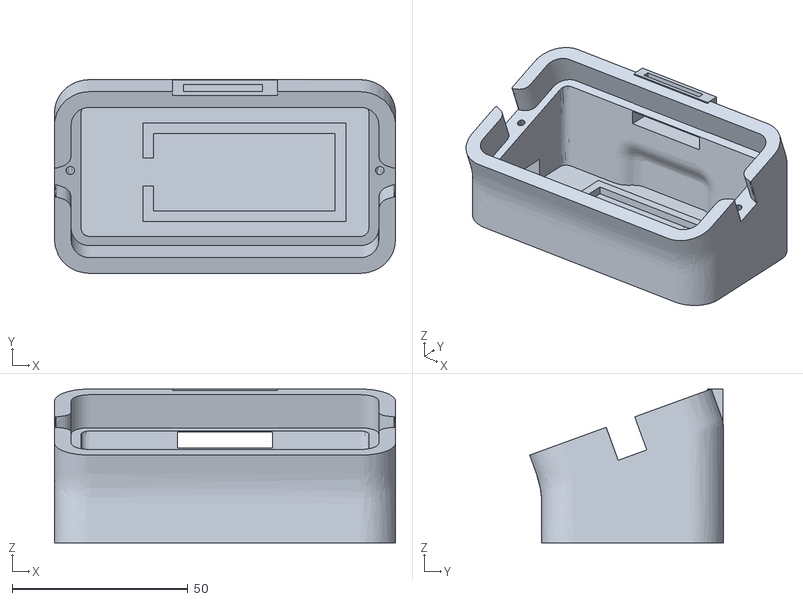
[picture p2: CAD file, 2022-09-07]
prints/Pico MacroPad + Oled.stl
97.0 x 55.1 x 43.8

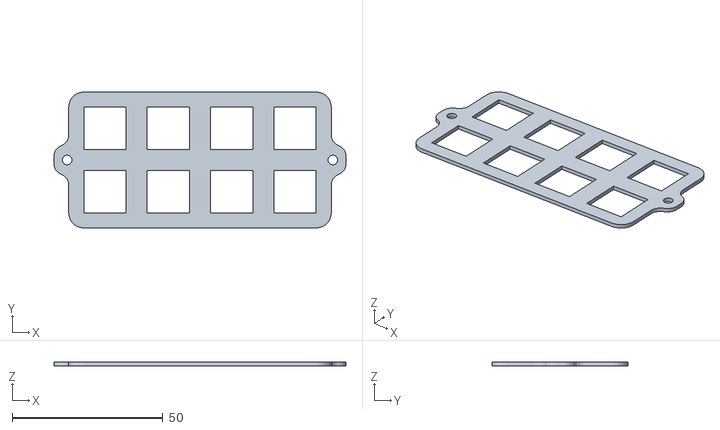
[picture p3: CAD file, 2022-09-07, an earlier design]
prints/_v1/baseplate/Retro Deck Baseplate.stl
96.8 x 45.0 x 1.27

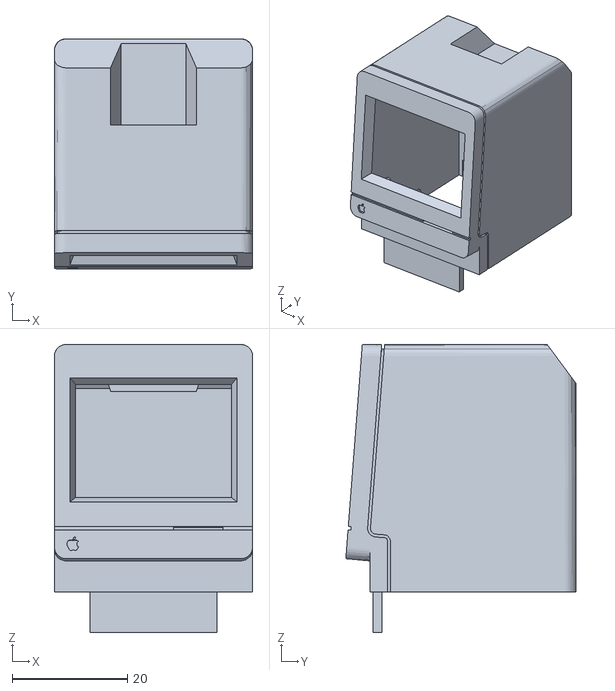
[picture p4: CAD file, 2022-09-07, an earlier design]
prints/_v1/monitor/Retro Deck Monitor.stl
34.4 x 40.0 x 50.0

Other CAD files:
prints/_v1/base/Retro Deck Base.stl

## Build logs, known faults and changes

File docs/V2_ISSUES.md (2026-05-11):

# Retro Deck V2 — Implementation Issues

> **Source:** `V2_PRD.md` (primary), `V2_REWRITE_ANALYSIS.md` (V1 context)
> **Total issues:** 17
> **Tracks:** deploy · firmware · host-daemon · config · config-ui · protocol

---

## Track overview and ordering

```
Deploy (#1)          ← standalone, do first — enables fast firmware iteration
Firmware (#2–6)      ← parallel with Host track; each builds on #2
Host (#7–13)         ← parallel with Firmware; #8 (config) is independent
Config UI (#14–16)   ← depends on HTTP API (#12); owner must confirm webapp vs TUI before #14
Claude Code (#17)    ← depends on HTTP API (#12); standalone integration
```

---

## Issue #1: Deploy Tooling

**Labels:** deploy
**Depends on:** none
**Effort:** M

### What & Why
Implements `bun run deploy` (`host/scripts/deploy.ts`) — the only sanctioned way to push firmware to the Pico. Without it, every firmware iteration requires manual CIRCUITPY mount/rsync/unmount steps. This is the first issue to tackle because a fast deploy loop (target: under 10 seconds) unblocks every other firmware issue.

### Acceptance Criteria
- [ ] `bun run deploy` detects the CIRCUITPY block device by filesystem label using `blkid -L CIRCUITPY` or `lsblk -o LABEL,PATH -nr` — never by hardcoded path
- [ ] Mounts the device (prefers `udisksctl mount`, falls back to `sudo mount`), creating the mountpoint if needed
- [ ] Reuses an existing mountpoint if the device is already mounted
- [ ] Runs `rsync -av --delete` from `firmware/` to the mount
- [ ] Calls `sync` then unmounts cleanly (`udisksctl unmount` + `udisksctl power-off` when available)
- [ ] Exits non-zero with a helpful message if no CIRCUITPY label is found
- [ ] Paranoia check: refuses to proceed if the resolved device label is not `CIRCUITPY`
- [ ] CLI flags: `--dry-run`, `--firmware <path>`, `--device /dev/sdX1` (override label detection)
- [ ] `package.json` exposes `bun run deploy` as the canonical command
- [ ] Total round-trip time under 10 seconds on a typical Pico

### Implementation Notes
Read PRD §8 in full before starting. Key gotcha: `--delete` on `rsync` to a wrong disk is catastrophic — the label check (and the paranoia re-check after mount) is the safety net. See §8.4 for the `udisksctl` vs `sudo` fallback pattern. The V2_REWRITE_ANALYSIS §8 notes `/dev/sda1` was the original plan — do not use it.

---

## Issue #2: Firmware Foundation — boot.py + asyncio Scaffold

**Labels:** firmware
**Depends on:** none
**Effort:** S

### What & Why
Creates the `firmware/` directory layout, `boot.py` (enables USB CDC data channel), and the skeleton of `code.py` (asyncio main with placeholder tasks). Without this, nothing else in the firmware track can be built or tested on hardware.

### Acceptance Criteria
- [ ] `firmware/boot.py` calls `usb_cdc.enable(console=True, data=True)` — no other logic
- [ ] After hard reset, `/dev/ttyACM0` (REPL) and `/dev/ttyACM1` (data) both enumerate on host
- [ ] `firmware/code.py` defines an `async def main()` that gathers four named tasks: `button_scanner_task`, `serial_reader_task`, `display_render_task`, `heartbeat_task`
- [ ] Each task is a stub (`async def ... : await asyncio.sleep(0)` loop) that compiles without error
- [ ] `firmware/retro/__init__.py` exists (can be empty)
- [ ] Module layout matches PRD §4.10 skeleton (empty files for `protocol.py`, `buttons.py`, `serial_io.py`, `display.py`, `hid.py`, `state.py`)
- [ ] No `time.sleep()` calls anywhere — every wait uses `await asyncio.sleep(...)`
- [ ] Device boots without dropping to REPL

### Implementation Notes
`boot.py` runs only at hard reset (power-cycle or RST button), not on soft-reload. This matters during development: after editing `code.py`, a soft-reload is enough; after editing `boot.py`, you must power-cycle. The asyncio module ships built-in with CircuitPython 8+ — do NOT add it to `lib/`. See PRD §4.2 and §4.7.

---

## Issue #3: Firmware — Button Scanner

**Labels:** firmware, protocol
**Depends on:** Issue #2
**Effort:** S

### What & Why
Implements the `button_scanner_task` using `keypad.Keys` for non-blocking, debounced edge detection. This is the primary input path — it produces the `button.press`, `button.hold`, and `button.release` events that drive everything else.

### Acceptance Criteria
- [ ] `firmware/retro/buttons.py` wraps `keypad.Keys` with the 8 GPIO pins from PRD §4.9 as a hardcoded constant
- [ ] `button_scanner_task` runs at ~100Hz and yields between polls (`await asyncio.sleep(0.01)`)
- [ ] Emits `press` event on leading edge; `release` event on trailing edge with `duration_ms`; `hold` event every 250ms after the first 500ms of held state
- [ ] Events include `id` (1–8, mapping from GPIO constant), `t` (`supervisor.ticks_ms()`), and `duration_ms` where applicable
- [ ] Events are placed onto an asyncio Queue that other tasks (serial_io, hid) can consume
- [ ] No `time.sleep()` in this module
- [ ] Pressing and releasing all 8 buttons in sequence produces 8 press + 8 release events without drops

### Implementation Notes
Use `keypad.Keys` (CircuitPython core module, not a library) — it handles debouncing internally so the task only needs to call `keys.events.get()` in a loop. The GPIO pins are GP20, GP19, GP18, GP17, GP11, GP12, GP13, GP14 for buttons 1–8 respectively (see PRD §4.9). `supervisor.ticks_ms()` is the timestamp source — not `time.monotonic()`. The hold-tick logic is in the scanner task, not in `keypad.Keys`.

---

## Issue #4: Firmware — Serial I/O (JSONL Framing + Handshake)

**Labels:** firmware, protocol
**Depends on:** Issue #2
**Effort:** M

### What & Why
Implements the JSONL read/write layer over `usb_cdc.data`, plus the `ready` handshake, `tick` heartbeat, `ping`/`pong`, `log`, and `error` message types. This is the protocol backbone — without it the host has no channel to or from the device.

### Acceptance Criteria
- [ ] `firmware/retro/serial_io.py` has a `serial_reader_task` that reads `usb_cdc.data` in a non-blocking loop, buffers bytes, splits on `\n`, and parses each line as JSON
- [ ] Lines longer than 1024 bytes are dropped with an `error` reply (`bad_json`, message explaining the drop)
- [ ] Unknown `type` values produce an `error` reply (`unknown_type`)
- [ ] Missing required fields produce an `error` reply (`bad_payload`)
- [ ] A write helper serializes any dict to `JSON.dumps(msg) + "\n"` and writes to `usb_cdc.data`
- [ ] On asyncio main start, firmware emits `{ "type": "ready", "protocol": 1, "app": "retro-deck", "buttons": 8, "display": { "w": 128, "h": 64 } }`
- [ ] `heartbeat_task` emits `{ "type": "tick", "t": <ticks_ms> }` every 5 seconds
- [ ] `ping` message is handled: replies immediately with `{ "type": "pong", "n": <echo>, "t": <ticks_ms> }`
- [ ] Received `hello` message is dispatched to an internal queue (consumed by bind and display subsystems in later issues)
- [ ] All errors are caught at task boundary — no unhandled exception crashes the firmware

### Implementation Notes
`usb_cdc.data` is the second serial endpoint (enabled by `boot.py`). In CircuitPython it behaves like a byte stream — use `.read(n)` with `in_waiting` to avoid blocking. The reader must be non-blocking: use `await asyncio.sleep(0)` inside the inner loop so other tasks get CPU time. The `ready` message is emitted once after `asyncio.gather` starts — not in `boot.py`. The full message catalogue is in PRD §9.

---

## Issue #5: Firmware — HID Emitter + Keypress Bindings

**Labels:** firmware, protocol
**Depends on:** Issue #3, Issue #4
**Effort:** S

### What & Why
Implements the `bind.set`, `bind.clear`, and `bind.clearAll` message handlers plus the HID emission logic. When a button with a `keypress` binding is pressed, the Pico fires the HID report immediately — no host round-trip — giving hardware-speed keystroke latency.

### Acceptance Criteria
- [ ] `firmware/retro/hid.py` maintains `keypress_bindings: dict[int, list[str]]` (button id → list of canonical Keycode names)
- [ ] `bind.set` message (`{ id, keys: [...] }`) populates the dict; unknown Keycode names reply with `error` (`bad_keycode`) naming the bad key, and the binding is rejected
- [ ] `bind.clear` removes the binding for a single button
- [ ] `bind.clearAll` clears the entire dict
- [ ] On a `button.press` event, if a binding exists for that button id, `Keyboard.send(*keycodes)` is called immediately, then keys are released after ~30ms
- [ ] Keycode names are resolved via `getattr(Keycode, name)` — validation at `bind.set` time prevents `AttributeError` at press time
- [ ] Buttons with no binding (or `bash`/`function`/`noop`) proceed normally — no HID emitted, event forwarded to serial_io for the host
- [ ] Both HID emission AND serial event forwarding happen for keypress buttons (host receives the event too)

### Implementation Notes
The host sends canonical names (e.g. `["CONTROL", "SHIFT", "R"]`) — the Pico only needs `getattr`. The alias table (mapping `ctrl` → `CONTROL`, etc.) lives on the host side (see PRD §6.4.1 and Issue #8/config loader). The Pico accepts only canonical names in `bind.set`. `adafruit_hid.keyboard.Keyboard` is already vendored in `lib/` from V1 — carry it forward unchanged.

---

## Issue #6: Firmware — OLED Display Renderer

**Labels:** firmware, protocol
**Depends on:** Issue #4
**Effort:** M

### What & Why
Implements the `display_render_task` and handlers for all `display.*` message types. The OLED shows the 3-zone layout (header / body / status) as instructed by the host — the Pico renders, never decides what to show.

### Acceptance Criteria
- [ ] `firmware/retro/display.py` manages a display state machine with three zones: header (line 1), body (lines 2–6), status (line 7)
- [ ] `display.layout` message renders: header = `message.header`, body = a 4×2 grid of 8 labels (buttons 1–4 top row, 5–8 bottom row), status = `message.status`
- [ ] Labels longer than 10 characters are truncated with `…`
- [ ] `display.toast` message replaces the body with the toast message in large font; after `ttl_ms` milliseconds, reverts to the last grid layout
- [ ] `display.status` updates only the status zone without disturbing the body
- [ ] `display.error` shows an inverted (white-on-black) error banner over the body until cleared
- [ ] `display.clearError` restores the body to the last grid layout
- [ ] Display updates are driven from the `display_render_task` which consumes a display state queue — no direct rendering in the serial reader task
- [ ] All rendering uses `terminalio.FONT` (built-in 6×8 monospace); no vendored text library required in v2.0
- [ ] The OLED shows a boot splash or blank on startup before the first `display.layout` from the host

### Implementation Notes
Use `displayio.Group` for scene management — swap the group's children rather than re-creating displays (mirrors the V1 `oled.py` `.pop()` pattern). The SSD1306 driver (`adafruit_displayio_ssd1306`) carries forward from V1. Toast TTL timing must use `supervisor.ticks_ms()` comparisons inside `display_render_task`'s loop, not `time.sleep()`. See PRD §4.5 for the 3-zone layout spec and §9.3 for all `display.*` message schemas.

---

## Issue #7: Host — Serial Port Manager

**Labels:** host-daemon, protocol
**Depends on:** none
**Effort:** M

### What & Why
Implements `host/src/serial/manager.ts` — the host-side serial connection lifecycle: device discovery, `ready` handshake, JSONL read/write loop, heartbeat stall detection, and auto-reconnect with backoff. This is the spine of the daemon — every other host module sends and receives via this manager.

### Acceptance Criteria
- [ ] Scans `/dev/ttyACM*` (and `/dev/serial/by-id/*` as a robustness pass); opens each non-busy candidate and listens for a `ready` line for up to 1500ms
- [ ] Accepts the first port that yields a valid `ready` with `protocol: 1` and `app: "retro-deck"`; ignores others
- [ ] Uses the `serialport` npm package (Node-compat in Bun); baud rate 115200 (ignored by USB CDC but required by the API)
- [ ] On receiving `ready`, emits `hello` (`{ "type": "hello", "protocol": 1 }`), then fires a `connected` event for other modules to hook
- [ ] Read loop buffers bytes, splits on `\n`, parses JSON, dispatches by `type` to registered handlers
- [ ] Write path serializes any object to `JSON.stringify(msg) + "\n"` and queues writes — never interleaves partial messages
- [ ] If no `tick` (or other message) is received for 15 seconds, closes the port and re-enters discovery
- [ ] On EOF or read error, backs off (250ms → 500ms → 1s → 2s → 5s max) and re-discovers
- [ ] On reconnect, fires `connected` event again (so other modules can re-push state)
- [ ] Malformed JSON lines: log error, emit `error` to device if possible, do not crash the read loop
- [ ] `manager.ts` exports a typed event emitter interface usable by `daemon.ts`

### Implementation Notes
The host does not send `ready` — it only listens for it from the Pico. The Pico always initiates. The 15-second stall threshold is 3 missed `tick` messages (tick period = 5s). Do not hard-code `/dev/ttyACM1` — it varies by enumeration order. The discovery window should try candidates serially (not in parallel) to avoid opening the REPL port. Full connect/reconnect sequence is in PRD §9.5.

---

## Issue #8: Host — Config Schema, Loader + Hot-Reload

**Labels:** config, host-daemon
**Depends on:** none
**Effort:** M

### What & Why
Implements the Zod schema (`host/src/config/schema.ts`), config loader (`loader.ts`), the keypress alias table, and hot-reload via `fs.watch`. This is the host's source of truth for user intent — every action dispatch and every profile switch flows through it.

### Acceptance Criteria
- [ ] Zod schema validates all fields from PRD §6.1–6.5, including: `version: 2`, at least one profile, all 8 button keys per profile, valid action types
- [ ] `keypress.key` parsing: lowercase, strip whitespace, split on `+`, map each token via the full alias table (PRD §6.4.1), validate each canonical name against the bundled Keycode name list
- [ ] Invalid canonical key name → schema validation error naming the bad token
- [ ] Config loaded from `~/.config/retro-deck/config.json` by default; overridable via `RETRO_DECK_CONFIG` env var
- [ ] On startup: read → validate → fail hard (exit non-zero) on invalid config
- [ ] `fs.watch` on the config file (debounced 250ms); on change: re-validate; if valid, swap in-memory config atomically and emit `configReloaded` event; if invalid, log error and keep previous config
- [ ] State persisted to `~/.local/share/retro-deck/state.json` (`{ activeProfile, lastUpdated }`); written atomically (write-tmp + rename) on every profile switch
- [ ] `state.json` read on startup to restore `activeProfile`; falls back to the first profile if absent or invalid
- [ ] First-run: if no `config.json` exists, copy `examples/config.example.json` to the user config dir
- [ ] TypeScript types derived from the Zod schema and exported from `types.ts`

### Implementation Notes
The keypress alias table is the full table in PRD §6.4.1 — implement it completely, not a subset. The "bundled Keycode name list" is a static `.ts` file generated from `adafruit_hid.keycode.Keycode` attribute names (can be hand-authored from the CircuitPython source; no runtime import needed). `function.module` paths are resolved relative to `dirname(configPath)`. See §6.5 for all validation rules and their failure modes.

---

## Issue #9: Host — Action Executor

**Labels:** host-daemon
**Depends on:** Issue #7, Issue #8
**Effort:** L

### What & Why
Implements `host/src/actions/executor.ts` — the dispatch logic for all action types (`keypress`, `bash`, `function`, `noop`) plus the per-button concurrency queue and timeout handling. This is where user intent becomes observable system behavior.

### Acceptance Criteria
- [ ] Listens to `button.release` events from the Serial Port Manager; determines short vs. long press using `duration_ms` and `config.device.longPressMs`
- [ ] Skips dispatch for `button.press` and `button.hold` (those are for live-state/SSE consumers only)
- [ ] `keypress` actions: log the event only — Pico has already fired HID. No host-side execution.
- [ ] `bash` actions: `Bun.spawn` with `bash -c <cmd>`, inheriting env plus `RETRO_DECK_BUTTON` and `RETRO_DECK_PROFILE`. Captures stdout/stderr to log. Status updates pushed to display controller every 1s during execution. Default timeout 30s (override per `action.timeoutMs`). On timeout: SIGTERM, then SIGKILL 5s later.
- [ ] `function` actions: `await import(absoluteModulePath)`, invoke default export with `ActionContext`. Module cached between presses; cache invalidated on config hot-reload or module file change. Return value `{ message }` used as success toast text.
- [ ] `noop` actions: emit a `✓ <button-label>` toast immediately.
- [ ] Per-button concurrency: at most 1 action in-flight + 1 queued per button. Further presses while both slots filled → "busy" toast and drop.
- [ ] Different buttons execute concurrently.
- [ ] `keypress` buttons never enter the concurrency queue.
- [ ] Success: `display.toast("✓ <action-name>", 1500)`; failure: `display.toast("✗ <error-summary>", 3000)`; timeout: `display.toast("✗ timeout", 3000)`.
- [ ] All stdout/stderr and errors logged to `~/.local/share/retro-deck/logs/`.

### Implementation Notes
For `function` hot-reload: use `fs.watch` on the module file path (resolved from config); on change, clear the cached module reference. The next press re-imports. One stale execution is acceptable if a press races the save — document this. For `bash`, the `cwd` default is `$HOME` (not the config dir). See PRD §5.4, §6.4.2, §6.4.3 for exact specs on each action type. The `ActionContext` type definition (PRD §6.4.3) must be exported for users writing `.ts` action modules.

---

## Issue #10: Host — Display Controller

**Labels:** host-daemon
**Depends on:** Issue #7
**Effort:** M

### What & Why
Implements `host/src/display/controller.ts` and `layouts.ts` — the component that owns "what should be on the OLED right now" and pushes the appropriate `display.*` messages to the Pico via the Serial Port Manager. Decoupled from action execution so any part of the system can request a toast or status update.

### Acceptance Criteria
- [ ] `DisplayController` accepts the current profile data and builds a `display.layout` message: `header` = profile label, `labels` = array of 8 button labels (in slot order 1–8), `status` = a status string
- [ ] On reconnect (`connected` event from Serial Port Manager): pushes `display.layout` and `display.status` to restore the Pico's display
- [ ] `toast(message, ttlMs?)` method: sends `display.toast` to the Pico
- [ ] `setStatus(message)` method: sends `display.status` to the Pico
- [ ] `showError(message)` / `clearError()`: sends `display.error` / `display.clearError`
- [ ] Labels longer than 10 chars are truncated to 9 chars + `…` before sending (host-side guard matching firmware behavior)
- [ ] After a profile switch, pushes updated `display.layout` within 100ms
- [ ] `DisplayController` exposes a simple event-based API so `ActionExecutor` can call `toast(...)` without importing Serial Port Manager directly

### Implementation Notes
The controller is a thin layer — it translates high-level intent ("show this profile") into protocol messages. It does not own a queue or retry logic; that's the Serial Port Manager's job. Profile label truncation on the host is a safety net — the Pico also truncates, but consistent behavior matters for the OLED preview in the config UI. See PRD §4.5 for the 3-zone layout and §9.3 for message schemas.

---

## Issue #11: Host — Profile Switch Logic

**Labels:** host-daemon
**Depends on:** Issue #8, Issue #9, Issue #10
**Effort:** S

### What & Why
Implements the profile cycling logic — detecting long-press on the configured `device.profileSwitchButton`, cycling through profiles in declaration order, persisting the new active profile, and pushing the full updated state to the Pico.

### Acceptance Criteria
- [ ] On `button.release` with `duration_ms >= config.device.longPressMs` and `id === config.device.profileSwitchButton`: treat as profile switch, not action dispatch
- [ ] Profile switching cycles through profiles in declaration order, wrapping at the end
- [ ] New active profile written to `state.json` atomically
- [ ] Full state push to Pico: `bind.clearAll` → `bind.set` for each keypress button in the new profile → `display.layout` with new profile labels → `display.toast("<new profile label>", 1500)`
- [ ] The switch button's short-press fires its configured action normally (no special handling)
- [ ] Profile switch completes within 100ms of the `release` event being received
- [ ] `POST /profiles/:name/activate` endpoint (see Issue #12) also routes through this same logic

### Implementation Notes
The `cycle` mode is the only mode required in v2.0. `menu` mode is deferred to v2.1 (PRD §6.3). The profile order for cycling is the key-insertion order of `config.profiles` (JSON object order — JavaScript preserves insertion order). The full bind push sequence matches the connect sequence from PRD §9.5.

---

## Issue #12: Host — HTTP API + SSE Stream

**Labels:** host-daemon
**Depends on:** Issue #8
**Effort:** M

### What & Why
Implements the HTTP control server (`host/src/http/server.ts`, `routes.ts`, `sse.ts`) binding on `127.0.0.1:7842`. This is the integration surface for the config UI and for external tools (Claude Code hooks, future integrations).

### Acceptance Criteria
- [ ] `Bun.serve` on `127.0.0.1:7842` (configurable via `config.http.host/port`)
- [ ] `GET /health` → `{ ok: true, connected: bool, activeProfile: string }`
- [ ] `GET /config` → current parsed config object
- [ ] `PUT /config` → replace config (validate, write to file, trigger hot-reload path); return 400 with validation errors on invalid input
- [ ] `GET /profiles` → array of `{ name, label }` objects
- [ ] `POST /profiles/:name/activate` → switch active profile; 404 if name not found
- [ ] `POST /buttons/:id/test` → trigger the action for button `id` in the active profile; 404 if id not in 1–8
- [ ] `GET /state` → `{ connected, activeProfile, lastEvent, lastError }`
- [ ] `GET /events` → SSE stream; emits events on button press/release/hold, profile switch, action result, connect/disconnect
- [ ] `POST /display/toast` → `{ message, ttl_ms? }` — push toast to OLED; return 202 immediately (non-blocking)
- [ ] `POST /display/prompt` → see Issue #17
- [ ] All endpoints return JSON; `Content-Type: application/json`
- [ ] Unrecognized routes → 404 JSON
- [ ] Server starts as part of daemon startup; port conflict → exit non-zero with clear message
- [ ] CORS headers set on all responses: `Access-Control-Allow-Origin: http://127.0.0.1:7843` (or `*` — localhost-only) so the config UI webapp can call the API from the browser

### Implementation Notes
The `/events` SSE stream is used by the config UI for live state sync — emit at minimum: `button-event`, `profile-changed`, `action-started`, `action-finished`, `device-connected`, `device-disconnected`. Bun has native SSE support via `Response` with a `ReadableStream`. The `/display/prompt` long-poll endpoint is in Issue #17 — wire the route stub here but the implementation lives there.

---

## Issue #13: Host — Daemon Entry Point + Lifecycle

**Labels:** host-daemon
**Depends on:** Issue #7, Issue #8, Issue #9, Issue #10, Issue #11, Issue #12
**Effort:** S

### What & Why
Implements `host/src/daemon.ts` — the entry point that wires all host modules together, manages startup sequencing, and handles SIGTERM/SIGINT for graceful shutdown. This is the final integration step that makes the daemon runnable as a single `bun run src/daemon.ts` command.

### Acceptance Criteria
- [ ] Startup sequence: load config → validate (exit non-zero on failure) → restore state → start HTTP server → start serial discovery
- [ ] On Pico `connected` event: push `bind.clearAll` + per-button `bind.set` + `display.layout` + `display.status("● ready")`
- [ ] Config hot-reload: on `configReloaded` event, re-push active profile state to Pico and emit a toast `config reloaded`
- [ ] On SIGTERM or SIGINT: send `display.toast("daemon stopped", 1500)`, wait 1.5s, close serial port cleanly, save state, exit 0
- [ ] Logs to stdout in a structured format (JSON lines or human-readable with timestamps); no file logging required at daemon entry level (action executor handles its own log file)
- [ ] Exits non-zero on fatal errors (invalid config, port conflict); exit code and message surfaced clearly
- [ ] `package.json` includes `"start": "bun run src/daemon.ts"` and `"dev": "bun --watch run src/daemon.ts"`
- [ ] 12-factor: foreground-by-default, all config via env/file, log to stdout

### Implementation Notes
The `--watch` dev mode is Bun's built-in hot-restart on file change — useful during development but should not be the production run mode (use a systemd user service). A sample `retro-deckd.service` unit file can be added to `examples/` but is not required for this issue. See PRD §5.2 for the full lifecycle spec.

---

## Issue #14: Config UI — Vite/React Scaffold + Live State Panel

**Labels:** config-ui
**Depends on:** Issue #12
**Effort:** M

### What & Why
Scaffolds the configuration webapp using **Bun.serve() + React — Tier 3A** per the project web stack standard (no Vite, no build step, dev = prod). Served on `127.0.0.1:7843`. Implements the live device state panel (connection status, active profile, recent button events) via SSE. This is the foundation the profile editor and OLED preview build on.

### Acceptance Criteria
- [ ] `Bun.serve()` + React project in `host/ui/` — no Vite, no `dist/` directory, no build step
- [ ] `host/ui/server.ts`: `Bun.serve({ routes: { "/": index }, development: { hmr: true } })` on `127.0.0.1:7843`
- [ ] `host/ui/index.html` loads `src/frontend.tsx` via `<script type="module">`; Bun bundles on the fly
- [ ] `package.json` adds `"ui": "bun run host/ui/server.ts"` — no `"ui:build"` script needed
- [ ] App connects to daemon `GET /events` SSE stream on load; reconnects automatically on disconnect
- [ ] Live state panel shows: device connected/disconnected indicator, active profile name, last 5 button events (id, type, timestamp)
- [ ] On device disconnect, the panel shows a "device disconnected" state (not an error crash)
- [ ] `GET /health` polled every 10s as a connectivity check; stale SSE connection detected via a 30s no-event timeout
- [ ] Two-pane layout: left sidebar = profile list with Activate buttons; right main area = profile editor (stub for Issue #15) + OLED preview (stub for Issue #16)
- [ ] App routes: `/` (root renders sidebar + default/active profile editor area), `/profiles/:name` (selects a profile in the editor)
- [ ] TanStack Query used for all REST data fetching against daemon API on port 7842

### Implementation Notes
Tier 3A: the UI has no own API — it only calls the daemon on port 7842. The daemon HTTP server (Issue #12) must set `Access-Control-Allow-Origin: http://127.0.0.1:7843` (or `*`). No Vite proxy, no build artifacts, no separate dev server. Bun's HMR (`development: { hmr: true }`) covers hot reload in dev. Use `EventSource` for SSE, TanStack Query for REST calls. Keep dep footprint minimal: React, TanStack Query, a router if needed.

---

## Issue #15: Config UI — Profile Editor (All Action Types)

**Labels:** config-ui
**Depends on:** Issue #14
**Effort:** L

### What & Why
Implements the core editing experience: browsing profiles, viewing and editing all 8 button slots per profile, with the right form for each action type — including the keypress capture affordance that motivated the webapp choice.

### Acceptance Criteria
- [ ] Profile list sidebar: shows all profiles with their labels; "Activate" button per profile (calls `POST /profiles/:name/activate`, SSE confirms switch); clicking a profile loads its 8-slot editor in the main area
- [ ] Profile editor main area: 8-slot button grid, each slot shows its label + action type badge; selecting a slot opens an inline editor panel
- [ ] Slot editor panel: editable label field; action type selector (keypress / bash / function / noop)
- [ ] `keypress` form: "Press keys" capture target (listens to `keydown` with modifiers — Ctrl, Shift, Alt, Meta); updates the `key` string in canonical `ctrl+shift+r` form; manual text entry fallback
- [ ] `bash` form: `cmd` text input, optional `cwd` and `timeoutMs` fields
- [ ] `function` form: `module` path input (relative to config file dir), optional `export` field
- [ ] `noop`: a single toggle / radio to select it (no additional fields)
- [ ] Inline validation: error messages shown per-field before save (e.g. unknown keycode, empty cmd)
- [ ] Changes are local until "Save" (Issue #16) — no auto-save

### Implementation Notes
The keypress capture is the primary reason for choosing webapp over TUI (PRD §7.2). The `keydown` handler needs to suppress browser defaults for the captured modifiers (`e.preventDefault()`) and should show a "recording" state. Map captured `e.key` / `e.code` + modifier flags to the alias table from PRD §6.4.1 to build the `key` string. Validation logic can mirror the daemon's Zod schema — consider sharing a `schema.ts` by importing it in the Vite build if the path resolution is clean.

---

## Issue #16: Config UI — OLED Preview + Test/Save Integration

**Labels:** config-ui
**Depends on:** Issue #14, Issue #15
**Effort:** M

### What & Why
Adds the OLED simulator preview pane (128×64 SSD1306-look CSS component showing what the current profile looks like on the device) and the "Test" button per slot plus the global "Save" flow with validation feedback.

### Acceptance Criteria
- [ ] OLED preview component: a 128×64px CSS-rendered "display" styled to look like an SSD1306 (dark bg, monochrome text); shows the 3-zone layout (header = profile label, body = 4×2 button grid, status line)
- [ ] Preview reflects live device state by default: header/labels/status mirror what the Pico is currently showing, sourced from SSE events (`display-layout`, `display-toast`, `display-status`)
- [ ] While the user is editing labels in the profile editor, the preview switches to "edit preview" mode — showing the locally-edited labels instead of live device state; reverts to live state on Save or Cancel
- [ ] Labels > 10 chars are shown truncated in the preview (matching firmware truncation)
- [ ] "Test" button per slot: calls `POST /buttons/:id/test`; shows a spinner while in-flight; shows success/error result
- [ ] "Save" button: collects the full edited config, calls `PUT /config`, shows validation errors inline on failure, shows a success toast on 200
- [ ] "Activate" button on profile list page works correctly (calls `POST /profiles/:name/activate`; SSE updates the live state panel)
- [ ] If the daemon returns a validation error on `PUT /config`, the specific field(s) are highlighted in the editor (not just a global error message)

### Implementation Notes
The OLED preview is a fixed-size `<div>` with a pixel-grid-like appearance — use CSS `font-family: monospace`, dark background, phosphor-green or white text, 128×64 aspect ratio. The label grid is 4 columns × 2 rows using CSS grid; truncate labels at 10 chars + `…` to match PRD §4.5. The "Test" call goes directly to the daemon API — it does not go through the firmware serial path, it's a daemon-level action trigger.

---

## Issue #17: Claude Code Hook Integration (/display/prompt)

**Labels:** host-daemon
**Depends on:** Issue #12
**Effort:** S

### What & Why
Implements the `POST /display/prompt` long-poll endpoint, which is the core Claude Code integration primitive: a hook can POST a prompt (with per-button option labels), block until the user presses one of the listed buttons, and receive back the chosen option — enabling the deck as an approval surface for agent workflows.

### Acceptance Criteria
- [ ] `POST /display/prompt` accepts `{ message: string, options: [{button: number, label: string}], timeout_ms?: number }`
- [ ] Pushes `display.layout` with per-slot labels overridden to show the option labels (other slots show blank or their normal label)
- [ ] Blocks (long-poll) until: one of the listed button ids is pressed (short-press), OR `timeout_ms` elapses (default 15000ms)
- [ ] On button press: returns `{ chosen: "<label>" }` (the label string, not the button id)
- [ ] On timeout: returns `{ chosen: null }`
- [ ] Restores the normal profile `display.layout` after resolution (whether pressed or timed out)
- [ ] Only one `/display/prompt` can be active at a time; a second call while one is pending returns 409 with `{ error: "prompt already active" }`
- [ ] `POST /display/toast` remains non-blocking (returns 202 immediately) — unchanged by this issue
- [ ] An example Claude Code hook config (the snippet from PRD §5.8) is documented in `examples/claude-hook.json`

### Implementation Notes
This endpoint is designed to be called by `curl` from a Claude Code hook command (see PRD §5.8 for the exact example). The long-poll approach means the HTTP connection stays open until resolved — Bun handles this well with `async` route handlers. The `/display/prompt` flow temporarily overrides the OLED display — make sure to restore it cleanly even if the daemon receives SIGTERM during the wait. The daemon does not need to know about Claude Code specifically; the integration is pure HTTP.

---

*End of V2_ISSUES.md*

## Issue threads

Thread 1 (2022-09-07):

STL File doesn't include the OLED Housing

markmcgookin, 2022-09-07:
I've imported the .stl file into both TinkerCAD and Shapr3D and neither of them seem to show up the housing for the OLED display that you showed on twitter, unless you didn't want to share that portion?

russell-davis, 2022-09-07:
Good catch! I'll add it today!

Closed 2022-09-07.

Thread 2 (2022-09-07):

STL file doesn't include the 'plate' for the switches

markmcgookin, 2022-09-07:
Loading the STL file into TinkerCAD and ShapR3D shows there isn't any 'plate' to mount the switches to. Could that be included please.

Closed 2022-09-07.

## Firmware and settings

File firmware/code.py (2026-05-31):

import board
import time
import usb_cdc
import json

serial = usb_cdc.data
serial.timeout = 0

VERSION = '2.1.0-diag'

_seq = 0


def send(msg):
    # Stamp every outbound message with a monotonic sequence number so the host
    # can detect dropped (seq gap) and duplicated (seq repeat) frames.
    global _seq
    _seq += 1
    msg['seq'] = _seq
    serial.write((json.dumps(msg) + '\n').encode('utf-8'))


send({'step': 'serial_ok'})

import keypad
send({'step': 'keypad_imported'})

import displayio
import busio
import terminalio
import adafruit_displayio_ssd1306
from adafruit_display_text import label
send({'step': 'display_libs_imported'})

PINS = [board.GP10, board.GP11, board.GP12, board.GP13,
        board.GP21, board.GP20, board.GP19, board.GP18]
IDS = [1, 2, 3, 4, 5, 6, 7, 8]

DEFAULT_DEBOUNCE_MS = 20

lbl_profile = None
lbl_action = None
display_ok = False

try:
    displayio.release_displays()
    send({'step': 'displays_released'})

    i2c = busio.I2C(board.GP1, board.GP0)
    send({'step': 'i2c_ok'})

    bus = displayio.I2CDisplay(i2c, device_address=0x3C)
    send({'step': 'i2c_display_ok'})

    display = adafruit_displayio_ssd1306.SSD1306(bus, width=128, height=64)
    send({'step': 'ssd1306_ok'})

    group = displayio.Group()
    lbl_profile = label.Label(terminalio.FONT, text="V2 ready", x=4, y=8)
    lbl_action = label.Label(terminalio.FONT, text="press a button", x=4, y=24)
    group.append(lbl_profile)
    group.append(lbl_action)
    display.show(group)
    send({'step': 'display_shown'})

    display_ok = True
except Exception as e:
    lbl_profile = None
    lbl_action = None
    display_ok = False
    send({'step': 'display_error', 'err': str(e)})

debounce_ms = DEFAULT_DEBOUNCE_MS
keys = None


def make_keys(ms):
    return keypad.Keys(PINS, value_when_pressed=False, pull=True, interval=ms / 1000)


try:
    keys = make_keys(debounce_ms)
    send({'step': 'keys_ok'})
except Exception as e:
    send({'step': 'keys_error', 'err': str(e)})

send({
    'type': 'ready',
    'version': VERSION,
    'buttons': len(IDS),
    'pins': ['GP10', 'GP11', 'GP12', 'GP13', 'GP21', 'GP20', 'GP19', 'GP18'],
    'debounce_ms': debounce_ms,
})

held = set()
buf = b''
heartbeat_ms = 0          # 0 = off; host enables it for diagnostics
last_tick = time.monotonic()


def apply_config(msg):
    global heartbeat_ms, debounce_ms, keys
    if 'heartbeat_ms' in msg:
        try:
            heartbeat_ms = int(msg['heartbeat_ms'])
        except Exception:
            pass
    if 'debounce_ms' in msg:
        try:
            new_ms = int(msg['debounce_ms'])
            if keys is not None:
                keys.deinit()
            debounce_ms = new_ms
            keys = make_keys(debounce_ms)
        except Exception as e:
            send({'type': 'error', 'where': 'config.debounce', 'err': str(e)})
    send({'type': 'config.ok', 'heartbeat_ms': heartbeat_ms, 'debounce_ms': debounce_ms})


while True:
    # Drain the ENTIRE keypad queue each loop. The old firmware took one event
    # per 10 ms tick, serializing near-simultaneous presses ~10 ms apart and
    # corrupting chord timing. Here every queued event is emitted immediately.
    if keys is not None:
        while True:
            ev = keys.events.get()
            if ev is None:
                break
            t = int(time.monotonic() * 1000)
            btn = IDS[ev.key_number]
            if ev.pressed:
                others = list(held)
                held.add(btn)
                send({'type': 'button.press', 'id': btn, 'held': others, 't': t})
            else:
                held.discard(btn)
                send({'type': 'button.release', 'id': btn, 't': t})

    if serial.in_waiting:
        buf += serial.read(serial.in_waiting)
        while b'\n' in buf:
            line, buf = buf.split(b'\n', 1)
            try:
                msg = json.loads(line)
                mtype = msg.get('type')
                if mtype == 'ping':
                    # Echo the host timestamp (ht) so the host can compute RTT.
                    send({'type': 'pong', 'id': msg.get('id'), 'ht': msg.get('ht'),
                          't': int(time.monotonic() * 1000)})
                elif mtype == 'display' and display_ok:
                    if 'line1' in msg:
                        lbl_profile.text = str(msg['line1'])[:20]
                    if 'line2' in msg:
                        lbl_action.text = str(msg['line2'])[:20]
                elif mtype == 'config':
                    apply_config(msg)
            except Exception:
                pass

    if heartbeat_ms:
        now = time.monotonic()
        if (now - last_tick) * 1000 >= heartbeat_ms:
            last_tick = now
            send({'type': 'tick', 't': int(now * 1000)})

    time.sleep(0.001)

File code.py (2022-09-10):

from src.rider_config import RiderConfig
from src.debug_buttons_functions import DebugButtonFunctions
from src.obs_buttons import OBSConfig
from src.oled import Oled
from src.register_buttons import setup_buttons
from src.fileUtilities import file_exists
import usb_hid
from adafruit_hid.keyboard import Keyboard
import time

# TODO: - Switch profile button
# TODO: - Companion App - Open specific apps
# TODO: - Profile for Launcher - Open specific apps
# TODO: - Profile for HomeKit actions
# TODO: - Profile for Webstorm actions


# Create the app configuration using the profile configurations
app_config = {
    "name": "RetroDeck",
    "version": "v1.0.0",
}

# Setup oled display
screen = Oled(app_config)
screen.set_standby()

# create the HID
kbd = Keyboard(usb_hid.devices)

# Create the profile configurations
debug_config = DebugButtonFunctions(screen, kbd)
rider_config = RiderConfig(screen, kbd)
obs_config = OBSConfig(screen, kbd)

configs = [
    debug_config,
    rider_config,
    obs_config
]

# current config
current_config = configs[0].config

# If there is a mappings.json file in the device root (beside code.py)
# it will be used to map the buttons. 
button_map = ""
if(file_exists('mappings.json')):
    with open('mappings.json', 'r') as file:
        button_map = file.read()

# Start listening for button presses
buttons = setup_buttons(button_map)

config_mode = False
quit_app = False

def handle_button_press(button):
    global config_mode
    global current_config
    config_changed = False
    key = buttons.index(button) + 1
    held_for = 0
    while not button.value:
        # if button held for 2 or more seconds, enter change to the profile at that index
        if held_for > 2:
            index = key - 1
            if configs[index]:
                cfg = configs[index]
                print("setting config to " + cfg.mode)
                cfg.print_name(key)
                current_config = cfg.config
                config_changed = True
                while not button.value:
                    time.sleep(0.01)
                    held_for += 0.01
                break
        time.sleep(0.01)
        held_for += 0.01
    print("button " + str(key) + " held for: " + str(held_for) + "s")
    
    if config_changed:
        return

    if key in current_config:
        action = current_config[key]["action"]
        if action:
            action(key)

while not quit_app:
    # perform the action for each button press
    for button in buttons:
        if not button.value:
            handle_button_press(button)
    time.sleep(0.01)  # sleep for debounce

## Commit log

2022-09-07 feat: add stl file (both)
    [Pico MacroPad + Oled.stl]
2022-09-07 feat: add v1 stl files
    [Retro Deck Base.stl, Retro Deck Baseplate.stl, Retro Deck Monitor.stl]
2022-09-08 Simpler OLED mount that is angled for ease of seeing the screen
    [Angled OLED Mount.stl]
2022-09-09 added ability to parse mapping file for buttons
2022-09-09 restored original button mapping defaults
2026-05-10 docs: V2 PRD, issues, and rewrite analysis
    PRD specifies host-owned brains, Pico as thin I/O peripheral; serial
    protocol (USB CDC, JSONL); three action types (keypress/bash/function);
    infinite named profiles with host-driven switching. Issues file breaks
    the work into trackable units; analysis captures the V1→V2 motivation
    and what got salvaged.
2026-05-10 feat(firmware): V2 firmware skeleton on Pico
    boot.py enables usb_cdc.data so the host can speak JSONL over a second
    ACM endpoint. code.py initialises the SSD1306, sets up keypad.Keys for
    8 buttons, and streams button.press/button.release events with a held-set
    for chording. Loop is intentionally minimal: no profiles, no labels,
    no action dispatch — the host owns all of that.
2026-05-10 feat(host): Tier 3A daemon scaffold
    One-process, one-port (7842) host daemon following the project's Web
    Stack Standard Tier 3A: Bun.serve with HTML imports, no Vite, dev=prod.
    Hono provides the API with chained-route type inference for the client
    RPC. SSE event stream at /api/events powers the live UI.
    Server pieces:
    - serial.ts spawns 'cat /dev/retrodeck' in a child process and consumes
    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
2026-05-10 feat(host/ui): profile switcher, button grid, live event log
    First UI slice on the Tier 3A scaffold. Components:
    - ProfileSwitcher: pill row reading /api/status, activates via
    POST /api/profile/:name
    - ButtonGrid + ButtonCard: 4x2 grid of all 8 slots from the active
    profile (via /api/config), per-card "Test" button fires
    POST /api/fire/:id/press, action-type tag (bash/keypress/profile/noop)
    - EventLog: tail of /api/events SSE with connection indicator
    - Press/hold events highlight the matching card amber for 250ms;
    release clears immediately. Per-id timers tracked in a ref so a
    newer press on a different button doesn't cancel the prior card's
    fade-out (the bug behind every previo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
2026-05-10 feat(host): execute keypress actions via ydotool
    Implements the keypress branch in dispatch.ts (was a console.log stub).
    Tokens from action.keys are looked up in a new keymap.ts (Linux input
    event codes from input-event-codes.h, scoped to what V2 uses: alpha,
    digits, function keys, common navigation/punctuation, modifiers).
    Emission protocol:
    - Modifiers are sorted first regardless of input order
    - Press all in order, sleep 30ms, release in reverse
    - Two ydotool spawns (press / release) — single-shot with -d would be
    marginally lower latency but two clean spawns is simpler and the
    Pico-side latency dominates anyway
    - Any unknown token aborts the whole dispatch (no partial keypress)
    -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
2026-05-10 docs: slice 2 PRD (binding editor + keypress dispatch)
    Implementation-ready spec for the inline binding editor (frontend) and
    keypress action execution via ydotool (backend). Closes the "edit
    binding -> press button -> action fires" loop. Does not move toward
    the full V2 PRD schema yet; that's slice 3.
2026-05-10 feat(host/ui): inline binding editor with per-type forms
    Click any button card to open a right-side drawer; pick action type
    from a 4-tab segmented control (Bash / Keypress / Profile / Noop), fill
    the form, save. Save does PUT /api/config with the next full Config
    built via setBinding(); daemon hot-reloads.
    - BindingDrawer: tab control, Esc + click-outside close, error inline,
    Saving… pending state. Switching tabs resets to that type's default
    empty action (intentional — user re-fills, no stale type leakage).
    - BashForm: label + cmd textarea; non-empty cmd required.
    - KeypressForm: label + Capture button. Capture listens for keydown
    globally and waits for a non-modifier key before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
2026-05-10 feat(host): action.result events + profile CRUD endpoints
    - dispatch signature now takes a 'slot' argument ('press' | 'hold').
    Both callers updated: api.ts /api/fire/:id/:slot passes through;
    server.ts serial handler passes 'press' (hold dispatch is wired
    for the future hold-slot work). Every branch emits exactly one
    action.result event with {buttonId, slot, action, ok, label?,
    durationMs, exitCode?, stderrTail?, message?} after resolution.
    - bash now pipes stderr (cap 4KB, last 200 chars surfaced on !ok)
    and drains stdout fire-and-forget to avoid pipe deadlock.
    - keypress propagates ydotool exit codes through and reports
    unknown-token errors in `message`.
    - profile/noop emit s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
2026-05-10 feat(host/ui): profile management + action.result toasts
    Closes the visual-feedback loop on action dispatch and gives profile CRUD a
    front door.
    - Toasts (App-level): subscribes to the existing useEventStream and renders
    one card per action.result event. Green border + 3s linger on ok,
    red border + 6s linger on !ok. Body shows result.message, falling back
    to stderrTail on failure. Stack newest-on-top, capped at 5, click to
    dismiss immediately, fade-out animation. Toasts share the action-type
    color tags used on cards.
    - ProfileSwitcher: kebab (⋯) appears on the active pill only — clicking
    opens ProfileMenu (Rename / Delete) anchored under the pill. A "+" pill
    at the end of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
2026-05-11 docs: slice 4 PRD (profile-cycle + hold-slot + manual keypress)
2026-05-11 feat(host/server): profile-cycle action — cycles through ordered profile list
2026-05-11 feat(host/ui): profile-cycle form, hold-slot editor, manual keypress string input
    Also fixes active profile pill joining with kebab button (flat right
    border-radius so the two elements connect flush).
2026-05-11 fix(host/ui): show kebab menu on all profile pills, not just active
    Inactive profiles now show the ⋯ menu so they can be renamed or deleted
    directly. Active profile delete remains disabled to prevent deleting the
    current profile.
2026-05-31 docs: slice 5 PRD — reliability + diagnostics
    Captures the two blockers (stuck-modifier keyboard hijack; mis-calibrated/duplicate input) with root causes, and the phased plan: reliability fixes, instrumented firmware, deploy tooling, then a data-driven smart input engine.
2026-05-31 feat(firmware): instrument input pipeline
    Add a monotonic seq on every message (host detects drops/dups); drain the entire keypad queue each loop and tighten the loop to ~1ms so near-simultaneous presses are no longer serialized ~10ms apart; report version/pins/debounce on ready; add a runtime config command (opt-in heartbeat, tunable keypad debounce); ping/pong echoes the host timestamp for RTT. Backward compatible — extra fields are ignored by existing host paths.
    [code.py]
2026-05-31 fix(host): eliminate stuck-modifier keyboard hijack
    Keypresses were two separate ydotool processes (press, wait, release); any interruption between them stranded a modifier held down system-wide. emitChord() now does press+release in ONE invocation. Add releaseAllModifiers() called on daemon startup (clears leaks from a crashed run) and exposed via POST /api/panic.
2026-05-31 fix(host): resolve CDC data port by interface, not the ambiguous symlink
    The Pico exposes two CDC interfaces sharing one serial (00=console, 02=data); the serial-only udev rule let /dev/retrodeck land on the console port. resolveDataPort() finds the interface-02 port via udevadm and re-resolves on every reconnect (handles re-enumeration after a reload). serial.ts uses it as the default. udev rule also pinned to ID_USB_INTERFACE_NUM==02.
2026-05-31 feat(host): deploy script + serial probe utility
    bun run deploy — find CIRCUITPY by label, mount via udisksctl, copy firmware + lib, sync (<10s, --eject to unmount). diag-probe.ts validates the instrumented firmware over serial (ping RTT, heartbeat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
2026-05-31 feat(host): diagnostics core + CLI + web tab (#6)
    Deliverable 1 — host/src/server/diagnostics.ts
    Pure, replayable DiagnosticsCore class (feed/summary/reset) and
    analyzeBatch() function. Computes drops, dups, press/release durations,
    inter-press gaps, offset-corrected latency jitter (arrivedAt-t series),
    throughput (events/sec), and ping RTT. No I/O — runs identically over
    a live feed or a recorded capture array.
    Deliverable 2 — host/scripts/diag.ts
    bun scripts/diag.ts <routine> — eight routines: tap, hold, double-tap,
    rapid-fire, chord, all-buttons, ping-stress, fork-bench. All serial-based
    routines use resolveDataPort() / RETRO_DECK_PORT. fork-bench measures
    host fork-per-keystroke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
2026-05-31 fix(host): exclude host-clocked SSE keepalive from latency offset series
    The daemon's /api/events keepalive ({type:'ping', t:Date.now()}) carries a
    host timestamp, while device messages carry device-monotonic t. Mixing them
    into the offset series corrupted the web tab's jitter metric. Guard on
    type !== 'ping'.
2026-05-31 feat(host): smart input engine — tap/hold/double-tap/chord classifier (#7)
    1. config.ts: new optional `input` block (InputConfigSchema) with defaults
    holdMs=500, doubleTapMs=250, chordWindowMs=40, debounceFloorMs=20.
    Backward compatible — existing config.json without `input` parses cleanly.
    2. input-engine.ts: pure InputEngine class with injected ScheduleTimer.
    Classifies raw press/release events into tap/hold/double-tap/chord gestures.
    Chord coalescing: buttons pressed within chordWindowMs fire ONE chord gesture
    and never emit standalone taps — fixes the double-fire race in the old handler.
    Hold timer fires after holdMs if button stays down; double-tap detected when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
2026-06-01 feat(host): live device RTT + honest jitter in diagnostics tab
    The daemon now pings the device once a second and stamps true round-trip
    latency (rtt) on each pong at serial-read time, so the web tab shows real
    device RTT instead of a blank — free of SSE/render delay. The core prefers
    this stamped rtt and falls back to arrivedAt-ht for the CLI's direct path.
    Replace the confusing 13-digit raw latency-offset line (device-monotonic vs
    host-epoch clocks made the absolute numbers meaningless) with a labeled
    delivery-jitter readout.
